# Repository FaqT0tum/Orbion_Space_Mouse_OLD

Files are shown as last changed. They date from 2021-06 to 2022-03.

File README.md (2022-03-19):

# Orbion The OpenSource Space Mouse






### Next news
- Neopixel Settings
- Scroll improvement
- Joystick improvement (the negative axes appear to have oversized values)
- Generic improvements (indicated by users)
- Cover screen improvement
- 3 rear button
- New knob support sistem

- The next firmware will be released in the (Release) section, on a date to be determined

<h1> THIS VERSION IS OBSOLETE </h1>

### go [here](https://github.com/FaqT0tum/Orbion_3D_Space_Mouse) for the new version

If you want to follow the live updates come to [Discord](https://discord.gg/tgut7grRTV)

### Version now available
- Body 2.2 (09/02/2022)
- Firmware 0.26.2 (13/02/2022)

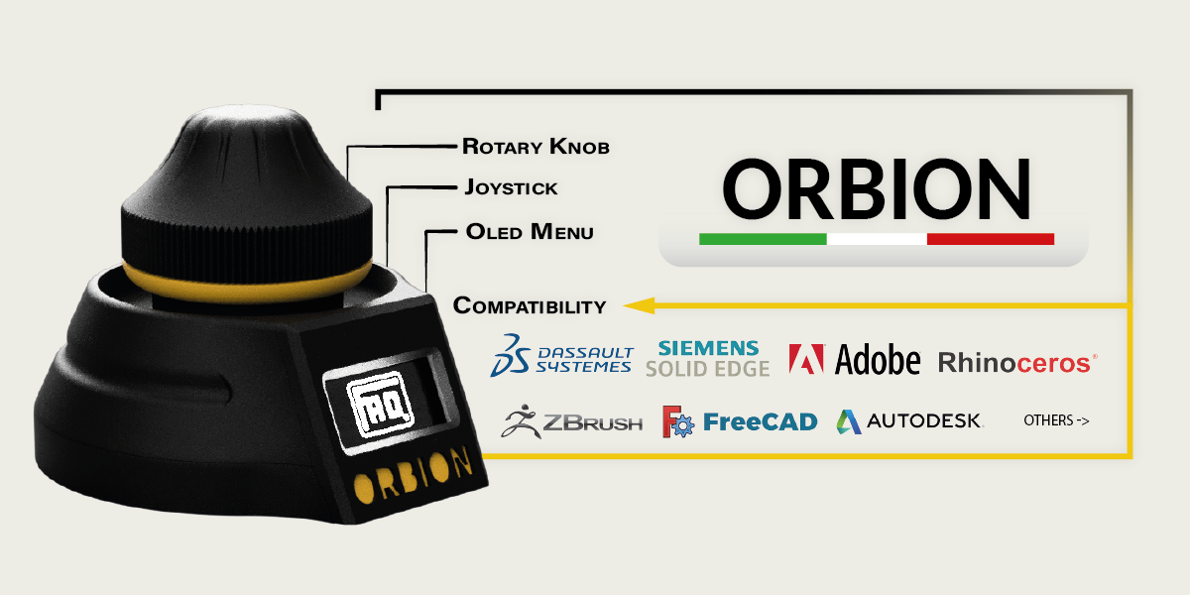
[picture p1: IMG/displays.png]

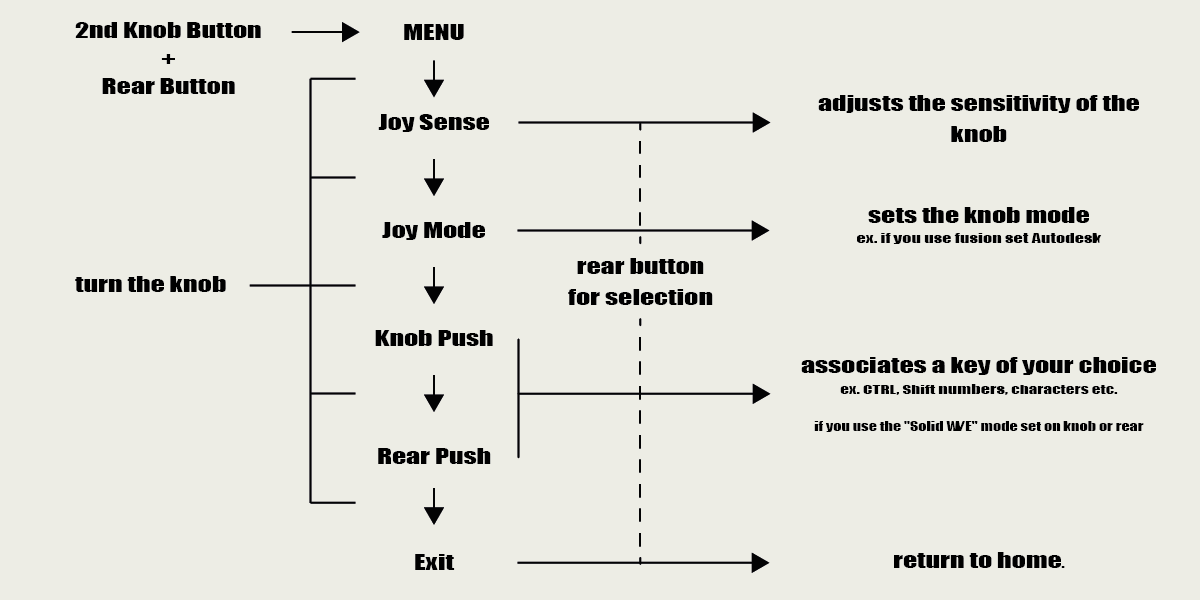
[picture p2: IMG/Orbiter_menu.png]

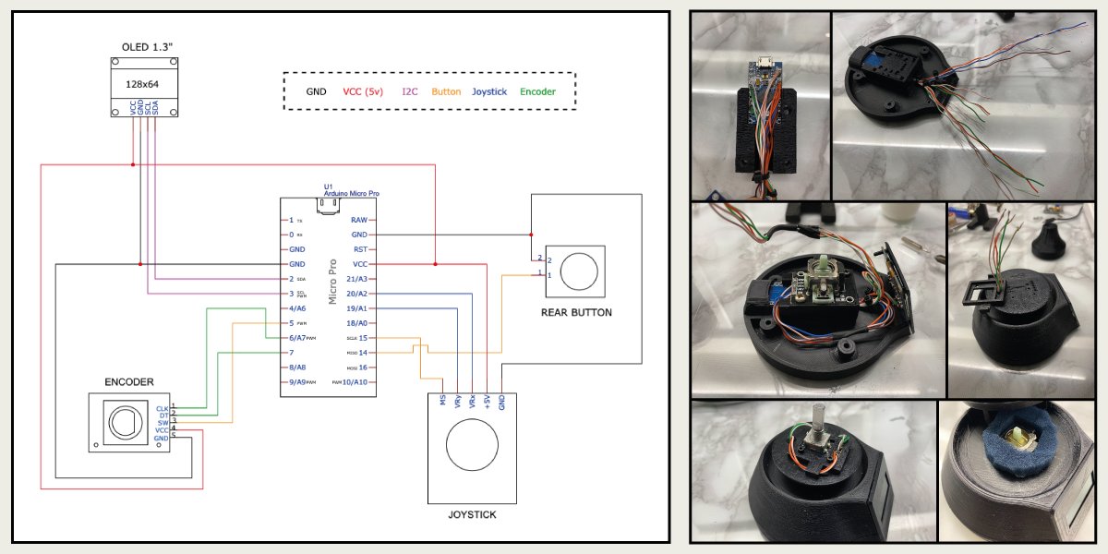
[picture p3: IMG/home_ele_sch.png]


## Cushion to be created in TPU to replace the FOAM. Designed by HiNATA

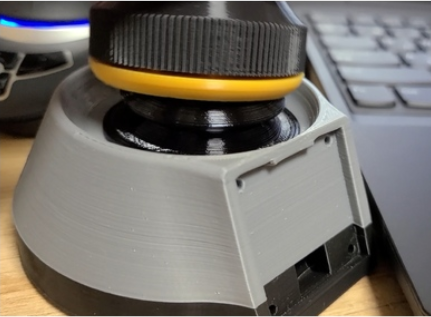
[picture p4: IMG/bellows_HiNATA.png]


Orbion (https://www.youtube.com/watch?v=NqHIdklkzfw&t "Orbion")

# PAY ATTENTION

Please note that only Rev2 is taken into consideration

For problems caused by badly produced components and wrong heights due to the calibration of printers not created Tickets as they are unique problems and not attributable to the project.

To ensure greater precision and fluidity it is recommended to put a foam ring under the knob (see photo above) and dielectric lubricant in the joystick!

If you notice that your joystick goes in different directions, you can change the direction, swapping the cables VRx and VRy or alternatively the variables horzPin and vertPin in the sketch (Find the joystick section above)

Before printing pay attention to the center distance of the encoder holes, 2 more diffuse sizes are available, 14mm and 17mm (file Enc_holder & Knob_axis)

I would like to point out that, if you use ABS it is good to know that some dimensions will not be correct if you do not take the usual precautions to the problem of shrinkage
In any case, make sure that your printer has the correct dimensional parameters

# Social

- [Instagram](https://www.instagram.com/faq_t0tum/)
- [Discord](https://discord.gg/tgut7grRTV)
- [YouTube](https://www.youtube.com/channel/UCHJ_528ZI0BcSU-QA8kIJlg)
- [PrusaPrinter](https://www.prusaprinters.org/social/218145-faqtotum/about)

# Buy me a coffee

The ORBION project is OpenSource so if you have the pleasure of supporting my next works I will be grateful fot the coffee.  
[PayPal](https://www.paypal.me/MattiaRusso308?locale.x=it_IT)

# Compatibility

Cad & 3D sculptors supported (continuously updated):
- Fusion360
- Autoocad
- SolidWork
- Solid EDGE
- Onshape
- Ansa
- ZBrush
- Blender
- Adobe Suite
- Rhino
- FreeCAD

# BOM

Componets:
- M3x15 (3pcs)
- M3x6 or M3x8 (2pcs)
- M3x10 (4pcs)
[M3 Kit](https://s.click.aliexpress.com/e/_9R4lDe)
- [Insert 5x4 or 5x5 (Diameter x Height) M3 (10pcs)](https://s.click.aliexpress.com/e/_9yVx2u)
- [Oled 1.3" I2C](https://s.click.aliexpress.com/e/_AtYDV6)
- [Encoder (KY-040)](https://s.click.aliexpress.com/e/_AmjV9a)
- [Joystick (KY-023)](https://s.click.aliexpress.com/e/_A8hY9K) (important: the joystick shaft must be 4mm)
- [Arduino Pro Micro](https://s.click.aliexpress.com/e/_AYt9zi) ATTENTION: It is essential to use ARDUINO PRO MICRO with ATMEL32U4 processor
- [Push Button 8mm](https://s.click.aliexpress.com/e/_ADGxZS)
- [Cable 28awg](https://s.click.aliexpress.com/e/_A6xGln)
- Foam

# License 
### [Attribution-NonCommercial-NoDerivatives 4.0 International](https://creativecommons.org/licenses/by-nc-nd/4.0/)
<br />

You are free to:
- Share — copy and redistribute the material in any medium or format

Under the following terms:
- Attribution — You must give appropriate credit, provide a link to the license, and indicate if changes were made. You may do so in any reasonable manner, but not in any way that suggests the licensor endorses you or your use.
- NonCommercial — You may not use the material for commercial purposes.
- NoDerivatives — If you remix, transform, or build upon the material, you may not distribute the modified material.

### If you have any other MODs you want to share, 
### log into the [Discord](https://discord.gg/tgut7grRTV) channel and contact me to add into "Yours_Creations"

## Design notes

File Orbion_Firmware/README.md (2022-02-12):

# Update 0.26.2

- improved scrolling in the menu
- Added a key combination to access the menu, to avoid accidental entry (Rear Button + second central button of the knob)

# Upload Orbion FIRMWARE on MCU

- Download and Installa Arduino IDE https://www.arduino.cc/en/software
- launch Arduino IDE and open the .ino file in the Orbion_FW_vX.XX folder (the icon.h file is also essential, so include it in the folder where the .ino file)
- Add the .ZIP libraries present in Orbion_FW_vX.XX/Library (Sketch -> #include library -> add library from .zip)
- select the board to use (Tools -> Board -> Arduino AVR Board -> Arduino Micro)
- select the port of your arduino (Tool -> Port -> (Arduino Micro) )
- now you are ready to upload the Firmware (Sketch -> Upload)
- now enjoy :)

#### Download only one version of the .ino file, for example the latest

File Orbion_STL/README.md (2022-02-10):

# NEW UPDATE (Rev. 2.2)

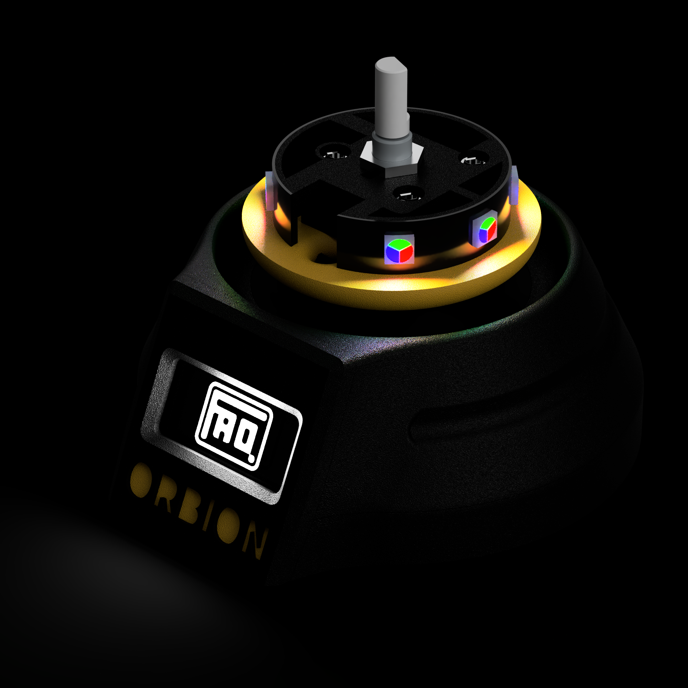
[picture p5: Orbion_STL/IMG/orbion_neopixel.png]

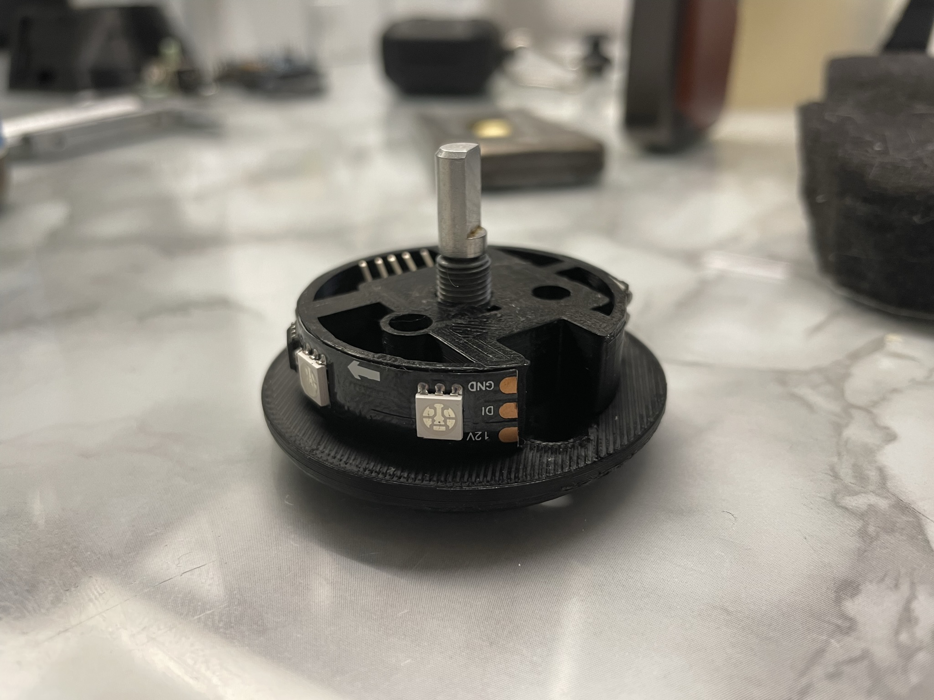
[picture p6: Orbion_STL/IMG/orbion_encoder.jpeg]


#### Don't mind the 12v led strip, it was just a fitting test
#### But the new Enc_holder remains essential to improve stability and rotation precision, so even without neopixels, the Enc_holder and Knob_axis_XXmm files must be printed.
### The Neopixels (WS2812b) have not been implemented yet, which will happen later

# Slicer

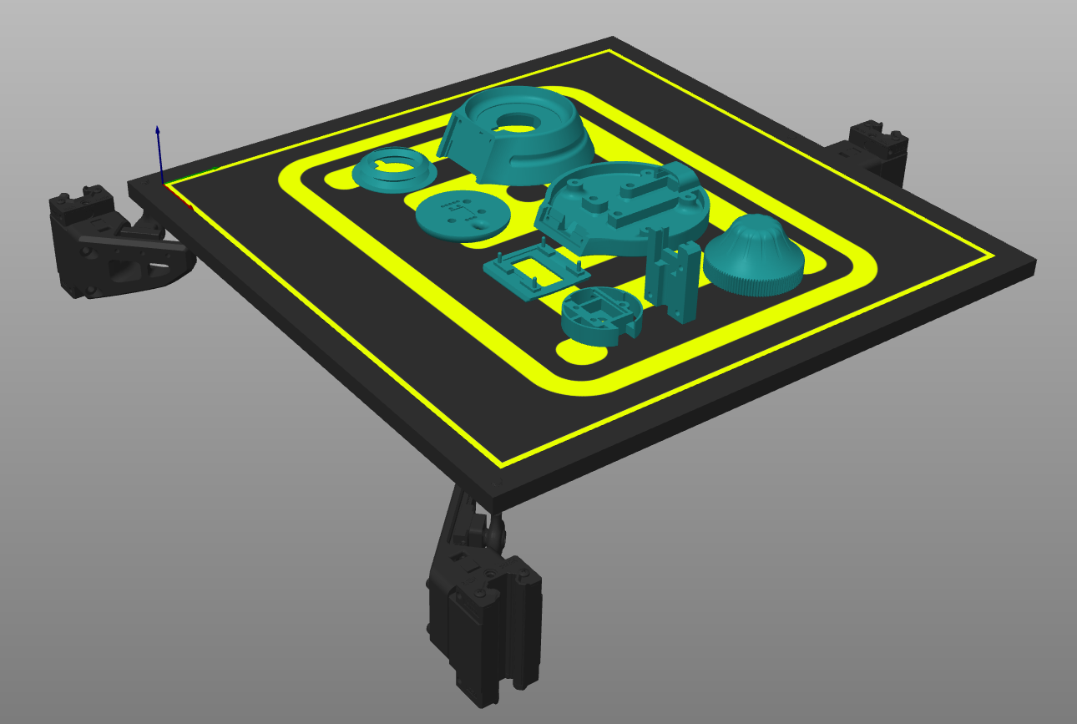
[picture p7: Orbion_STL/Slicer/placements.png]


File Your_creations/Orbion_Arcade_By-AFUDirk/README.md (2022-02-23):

# Orbion MOD (Arcade) With 6 Push button By AFUDirk

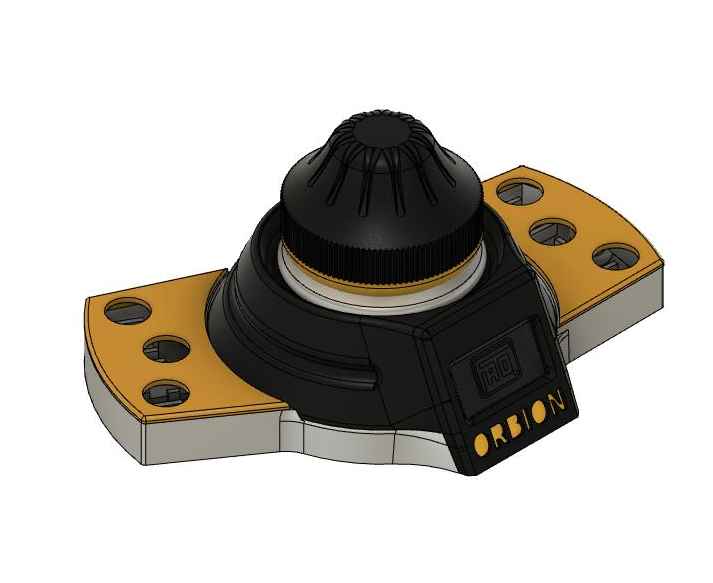
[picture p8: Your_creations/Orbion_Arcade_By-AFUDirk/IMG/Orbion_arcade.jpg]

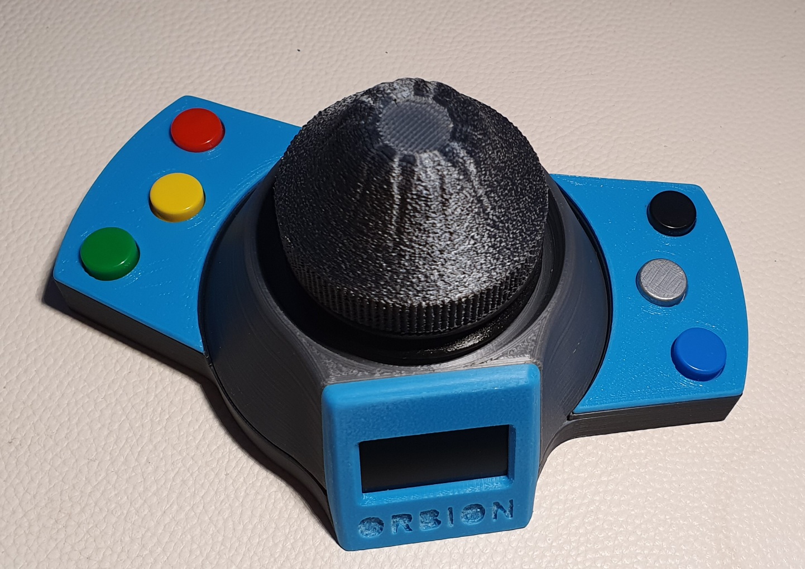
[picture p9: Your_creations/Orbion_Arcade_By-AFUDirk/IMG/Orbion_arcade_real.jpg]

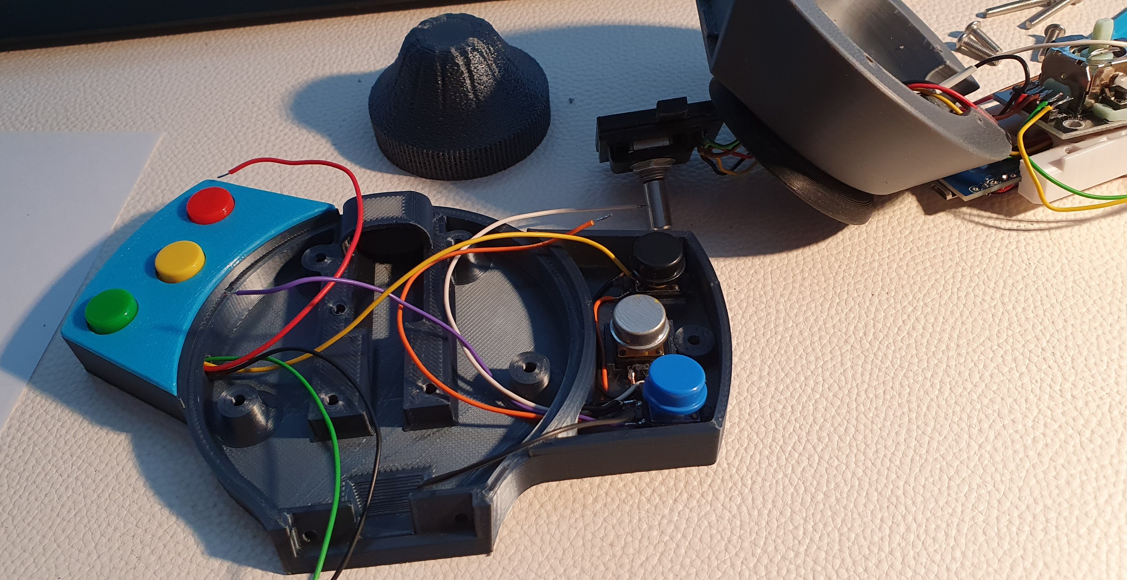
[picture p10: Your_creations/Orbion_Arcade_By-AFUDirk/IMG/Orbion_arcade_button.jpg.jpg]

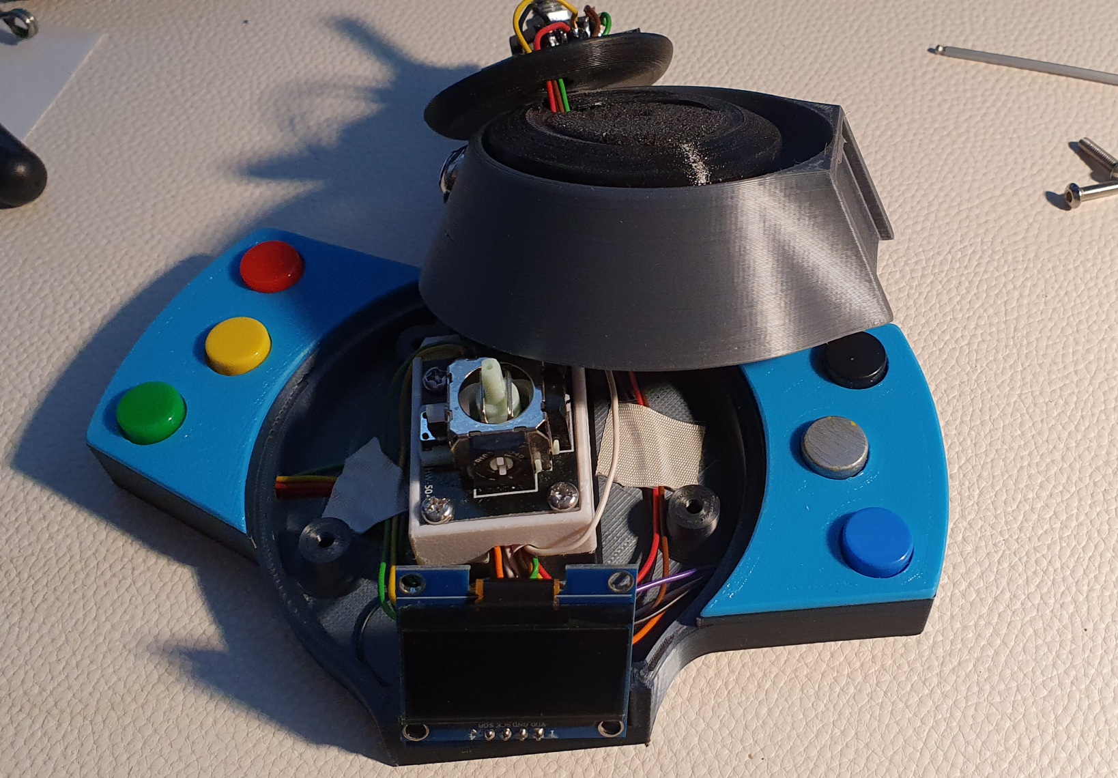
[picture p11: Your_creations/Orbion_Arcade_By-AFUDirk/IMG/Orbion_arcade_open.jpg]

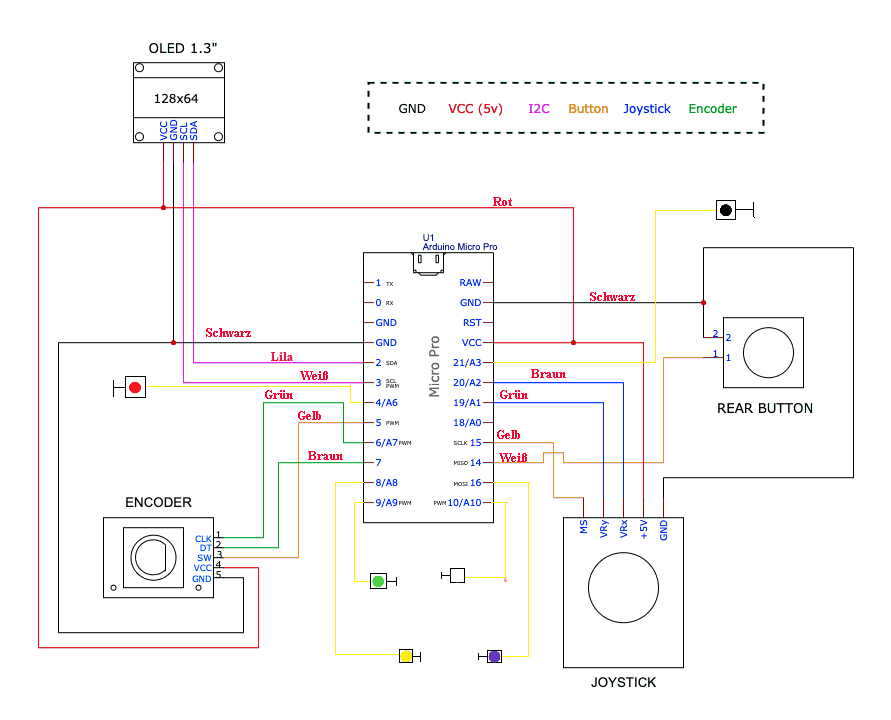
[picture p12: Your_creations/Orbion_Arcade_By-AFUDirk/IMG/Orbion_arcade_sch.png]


# BOM

Componets:
- M3x15 (3pcs)
- M3x6 or M3x8 (2pcs)
- M3x10 (4pcs) 
[M3 Kit](https://s.click.aliexpress.com/e/_9R4lDe)
- [Insert 5x4 or 5x5 (Diameter x Height) M3 (10pcs)](https://s.click.aliexpress.com/e/_9yVx2u)
- [Oled 1.3" I2C](https://s.click.aliexpress.com/e/_AtYDV6)
- [Encoder (KY-040)](https://s.click.aliexpress.com/e/_AmjV9a)
- [Joystick (KY-023)](https://s.click.aliexpress.com/e/_A8hY9K) (important: the joystick shaft must be 4mm)
- [Arduino Pro Micro](https://s.click.aliexpress.com/e/_AYt9zi) ATTENTION: It is essential to use ARDUINO PRO MICRO with ATMEL32U4 processor
- [Rear push Button 8mm](https://s.click.aliexpress.com/e/_ADGxZS)
- [Push Button 8mm 6pcs](https://s.click.aliexpress.com/e/_A5RW7d)
- Foam
- Cushion (Printable in TPU)

I designed a macro keyboard that extends the ORBION_SPACE_MOUSE,
because the Arduino installed there still had many unused connections.
I have assigned the six keys with the following functions that are used frequently.
-L for line
-C for circle
-R for rectangle
-E for extrusion
-Q for push/pull
-Shift and 1 for four views preview

The buttons can be assigned as desired in the Arduino code.
The attached Arduino code refers to version 0.26.03.
The attached fusion file can be inserted into the existing project and connected to the base of the ORBION.
The two halves of the keyboard can be used if necessary depending on which version you use (MICO-USB or USB-C).
Please don't forget to add the two holes to the ORBION to attach the cables to perform.

### If you need a hand and clarification you will find the creator on 
[Discord](https://discord.gg/tgut7grRTV)

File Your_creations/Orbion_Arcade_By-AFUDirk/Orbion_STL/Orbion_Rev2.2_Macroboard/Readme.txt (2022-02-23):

I designed a macro keyboard that extends the ORBION_SPACE_MOUSE,
because the Arduino installed there still had many unused connections.
I have assigned the six keys with the following functions that are used frequently.
L for line
C for circle
R for rectangle
E for extrusion
Q for push/pull
Shift and 1 for four views preview

The buttons can be assigned as desired in the Arduino code.
The attached Arduino code refers to version 0.26.03.
The attached fusion file can be inserted into the existing project and connected to the base of the ORBION.
The two halves of the keyboard can be used if necessary depending on which version you use (MICO-USB or USB-C).
Please don't forget to add the two holes to the ORBION to attach the cables to perform.

I used these buttons:
GTIWUNG (12 x 12 x 7.3mm) Pushbutton Switch, Micro Momentary Pushbutton Switch,
4 pin micro switch, with cap for Arduino.
AMAZON: https://www.amazon.de/dp/B08VNB6BX5/ref=cm_sw_em_r_mt_dp_BYXSJA3T0259SFX7PPZY?_encoding=UTF8&psc=1

or

ALIEXPRESS:
https://www.aliexpress.com/item/32834276752.html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 %22sku_id%22%3A%2265072909447%22%7D&pdp_pi=-1%3B1.54%3B-1%3B-1%40salePrice%3BEUR%3Bsearch-mainSearch

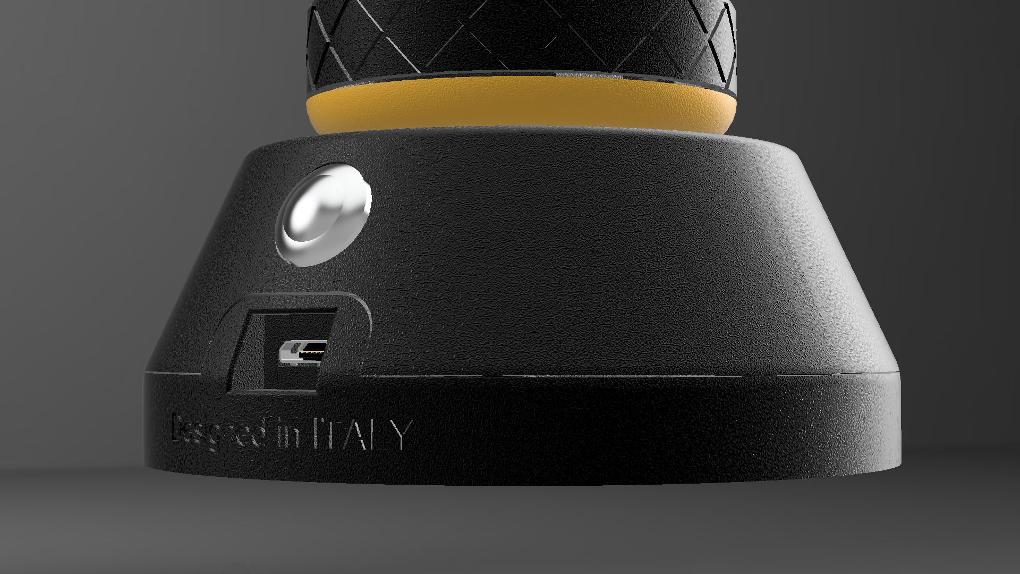
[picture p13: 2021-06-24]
IMG/Orbion_rear.png

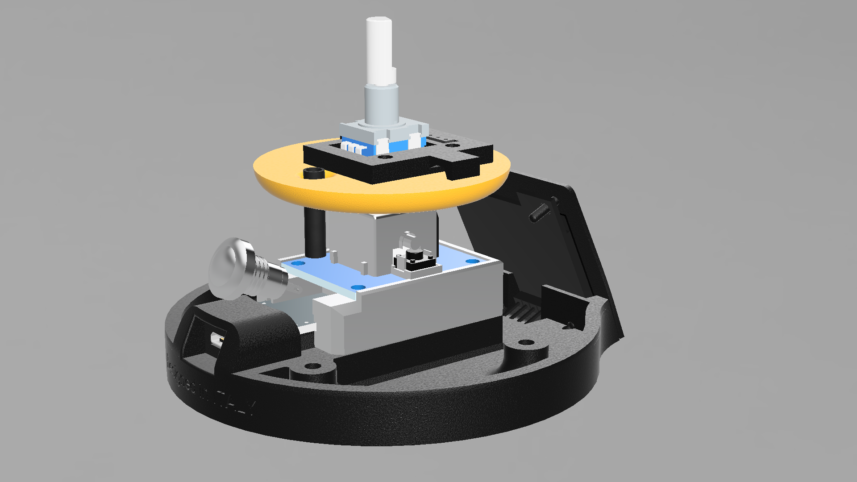
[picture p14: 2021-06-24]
IMG/Orbion_inner.png

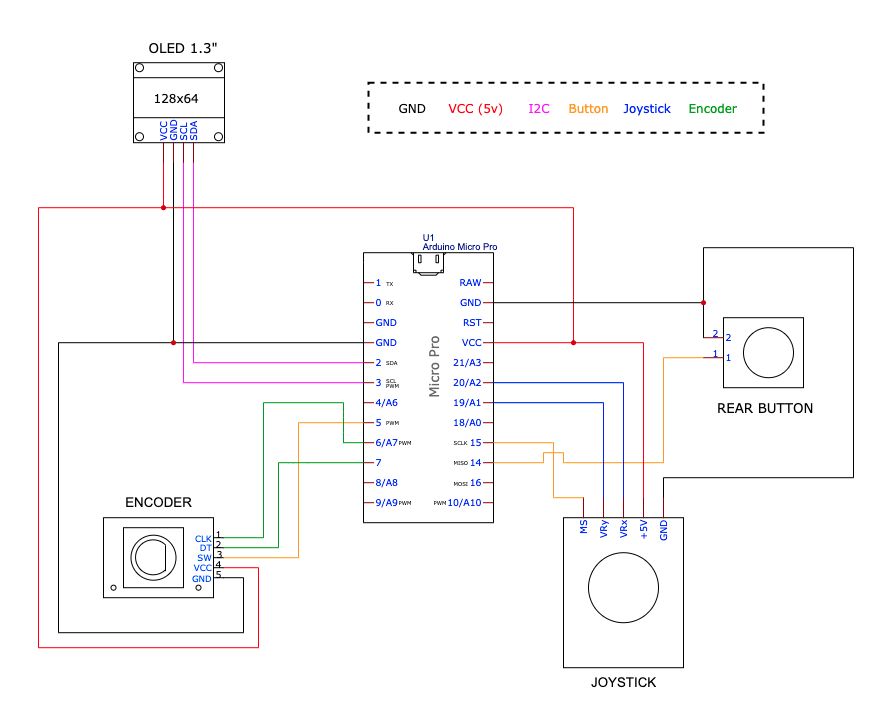
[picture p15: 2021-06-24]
IMG/Orbion_(SCH).png

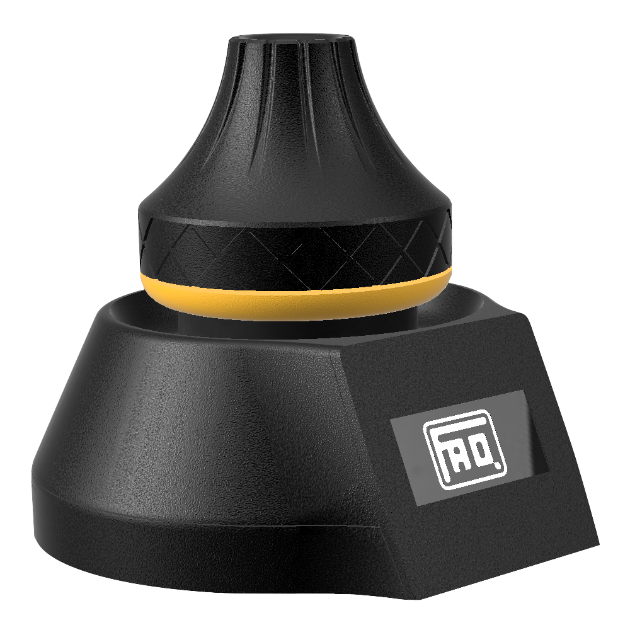
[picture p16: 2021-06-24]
IMG/Orbion.png

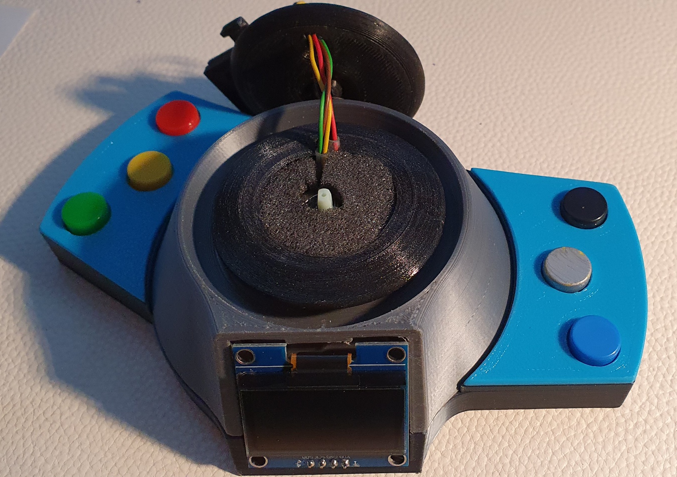
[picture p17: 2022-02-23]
Your_creations/Orbion_Arcade_By-AFUDirk/IMG/Orbion_Balg.jpg

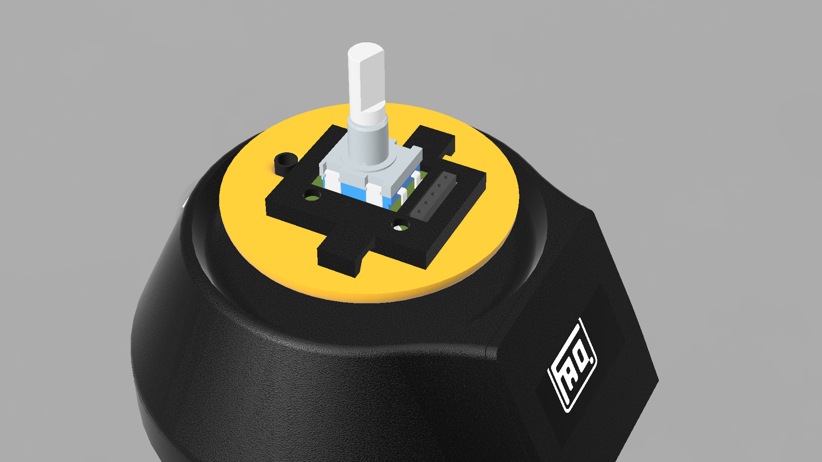
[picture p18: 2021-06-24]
IMG/Orbion_enc.png

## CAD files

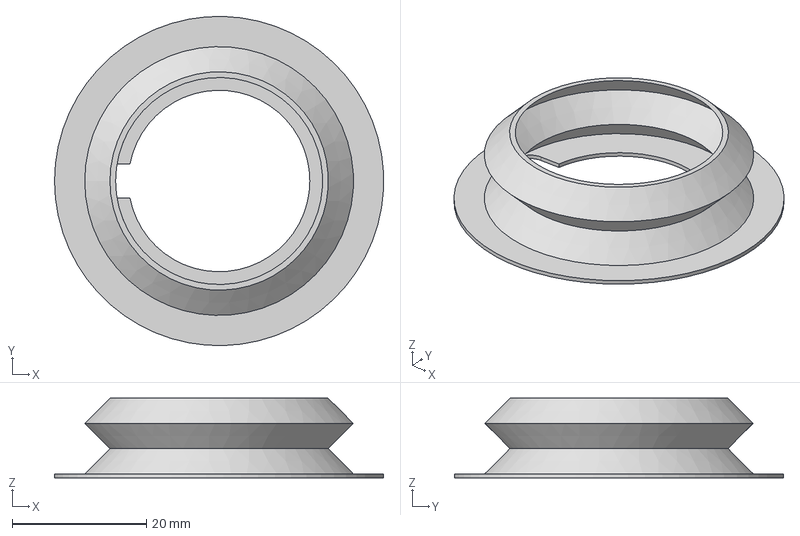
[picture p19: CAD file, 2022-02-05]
Orbion_CAD/Bellow_HiNATA.step
49.0 x 49.0 x 11.9 mm

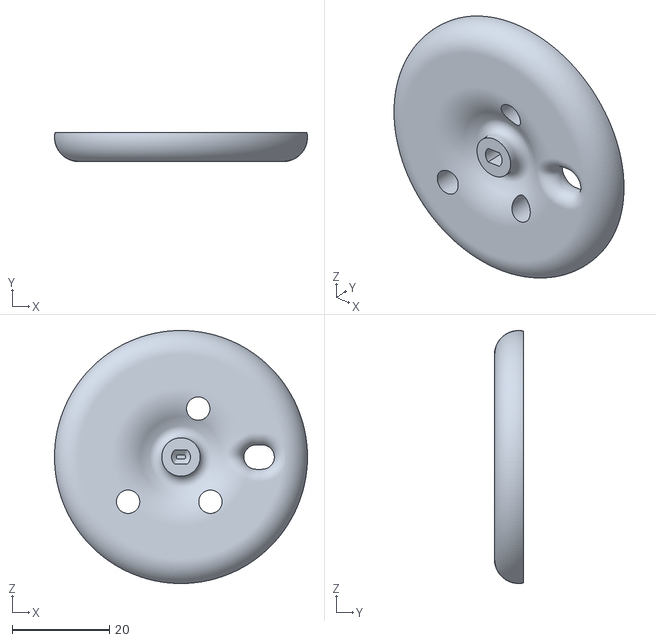
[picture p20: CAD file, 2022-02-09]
Orbion_STL/Orbion_Rev2.2/Knob_Axis_17mm.stl
52.0 x 6.01 x 52.0

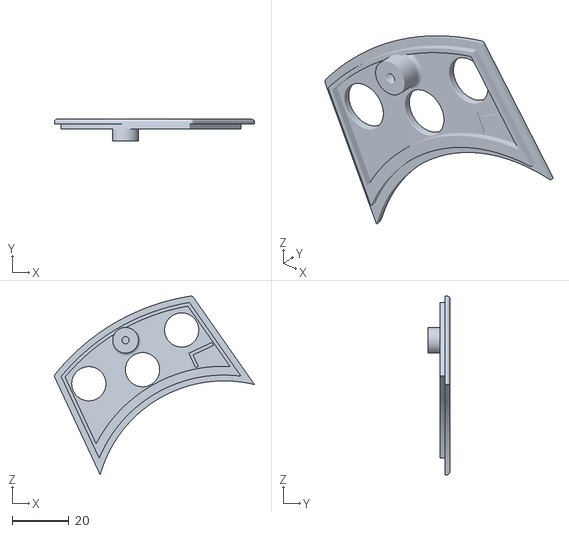
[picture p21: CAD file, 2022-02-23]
Your_creations/Orbion_Arcade_By-AFUDirk/Orbion_STL/Orbion_Rev2.2_Macroboard/Cover_left.stl
70.4 x 7.77 x 62.9

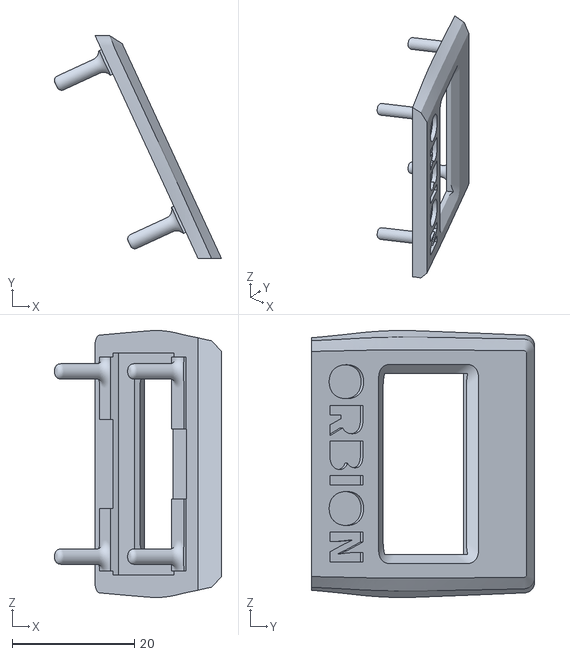
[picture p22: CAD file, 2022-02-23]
Your_creations/Orbion_Arcade_By-AFUDirk/Orbion_STL/Sceen_cover.stl
27.4 x 36.6 x 43.7

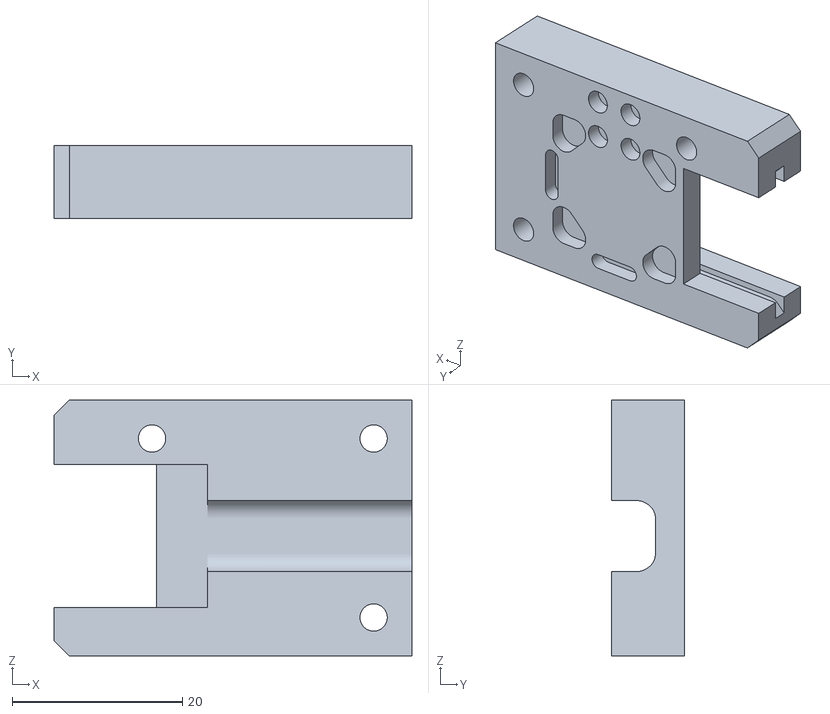
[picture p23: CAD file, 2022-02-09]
Orbion_STL/Orbion_Rev2.2/Supp_ele_Micro_USB.stl
42.0 x 8.55 x 30.0

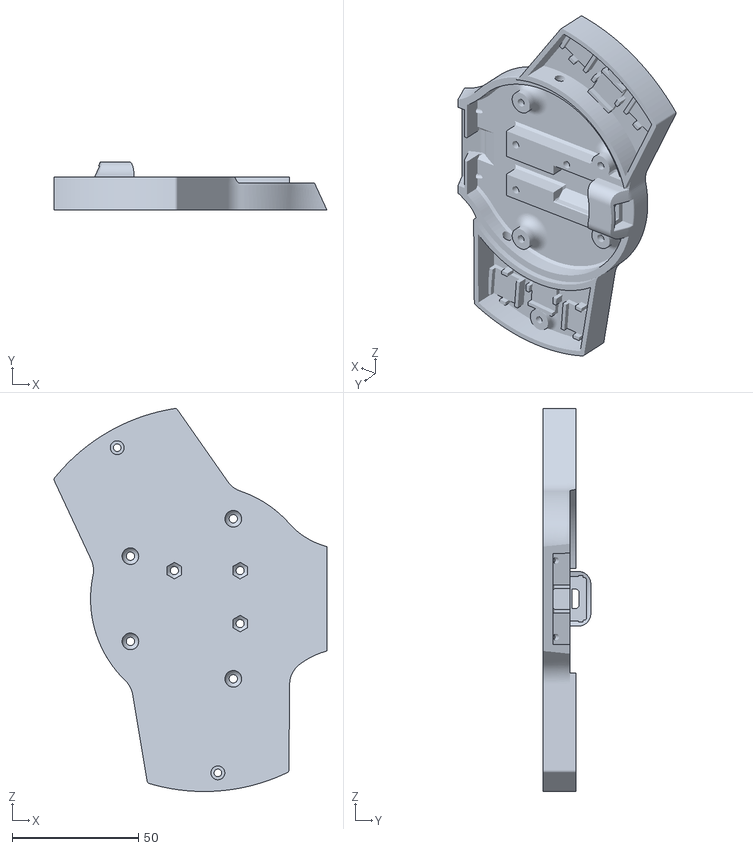
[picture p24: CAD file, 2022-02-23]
Your_creations/Orbion_Arcade_By-AFUDirk/Orbion_STL/Base_Macroboard.stl
108.0 x 18.9 x 151.7

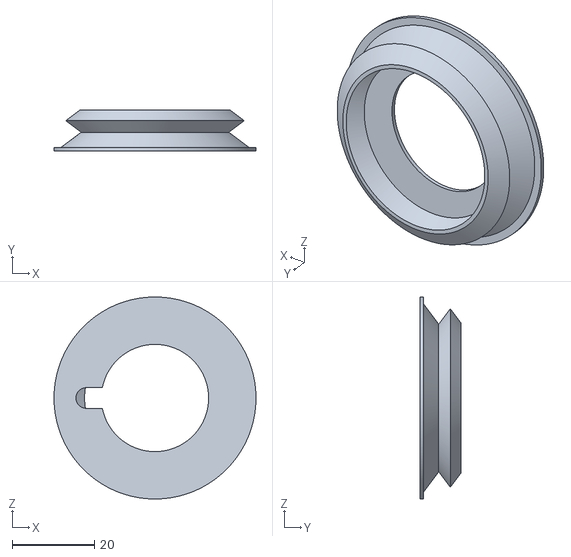
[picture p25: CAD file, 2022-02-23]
Your_creations/Orbion_Arcade_By-AFUDirk/Orbion_STL/Orbion_Rev2.2_Macroboard/bellows.stl
49.0 x 9.89 x 49.0

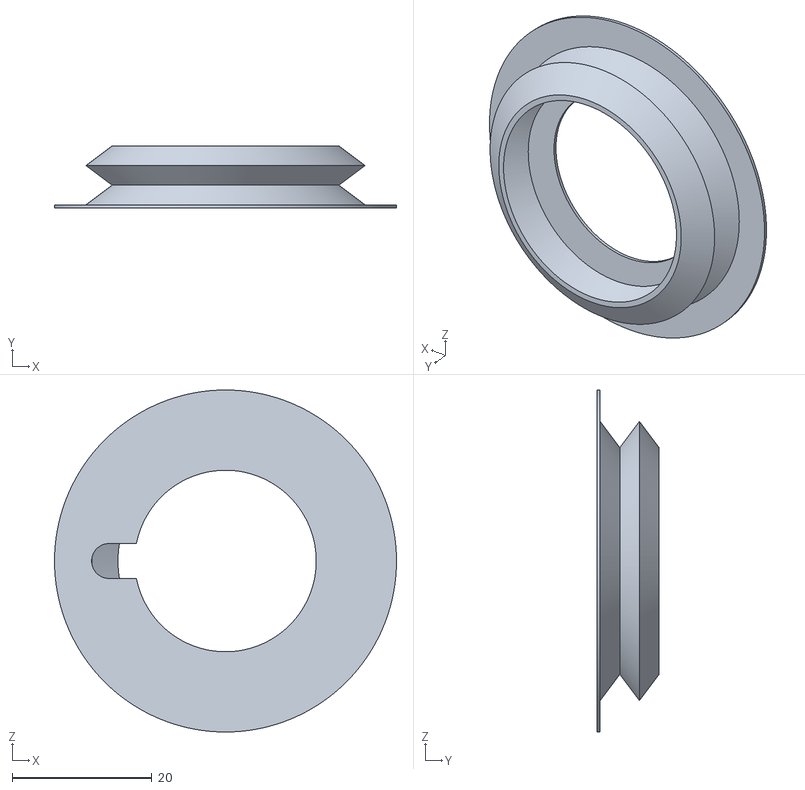
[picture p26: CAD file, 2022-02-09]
Orbion_STL/Orbion_Rev2.2/Cushion_HiNATA.stl
49.0 x 8.89 x 49.0

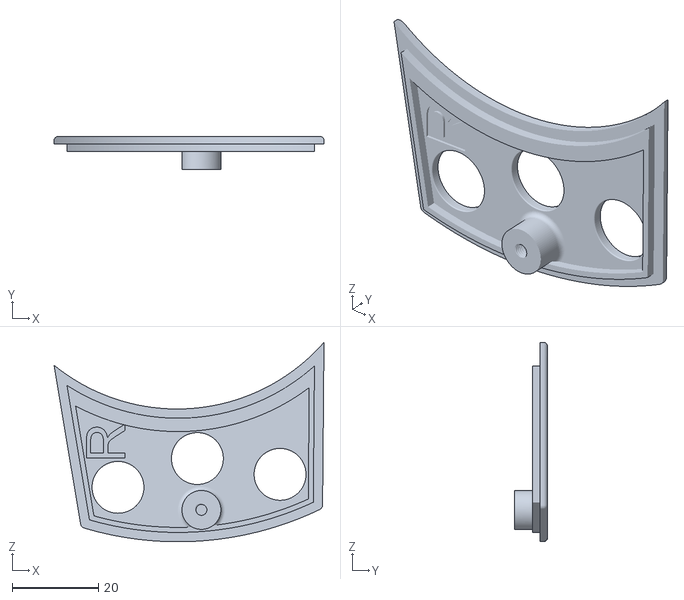
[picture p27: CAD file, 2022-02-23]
Your_creations/Orbion_Arcade_By-AFUDirk/Orbion_STL/Oberteil_re.stl
62.7 x 7.77 x 46.3

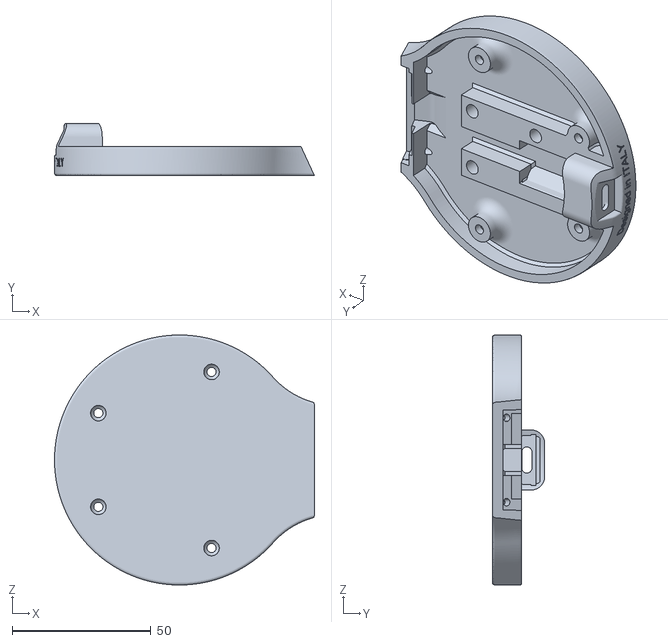
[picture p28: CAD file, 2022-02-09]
Orbion_STL/Orbion_Rev2.2/Base_TypeC_BETA.stl
93.6 x 18.9 x 90.0

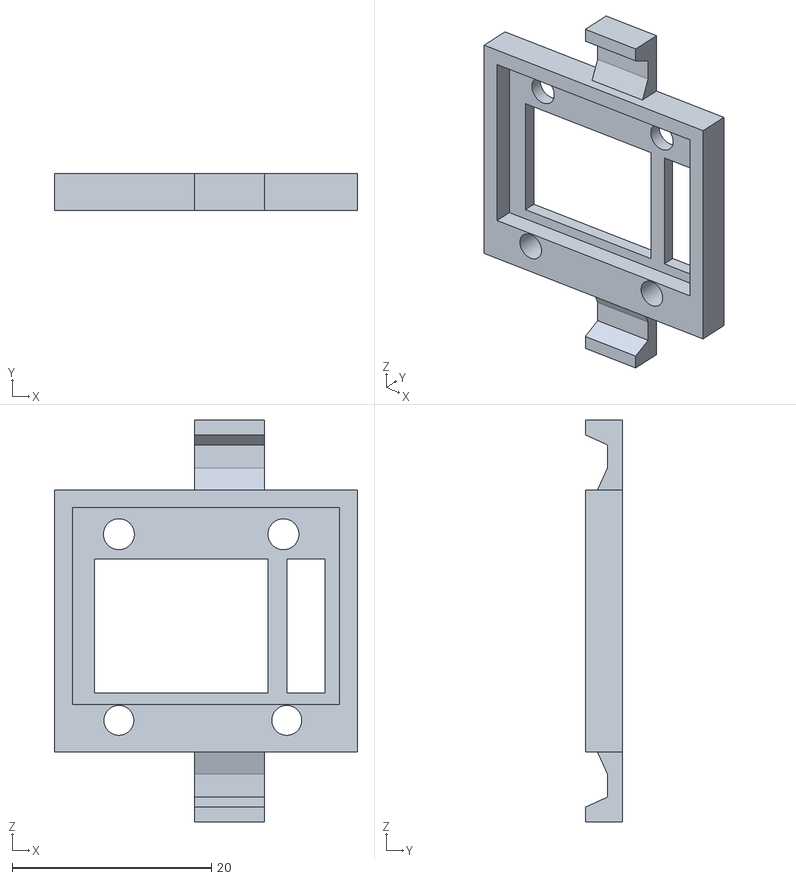
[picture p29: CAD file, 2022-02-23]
Your_creations/Orbion_Arcade_By-AFUDirk/Orbion_STL/Encoder_holder.stl
30.4 x 3.70 x 40.3

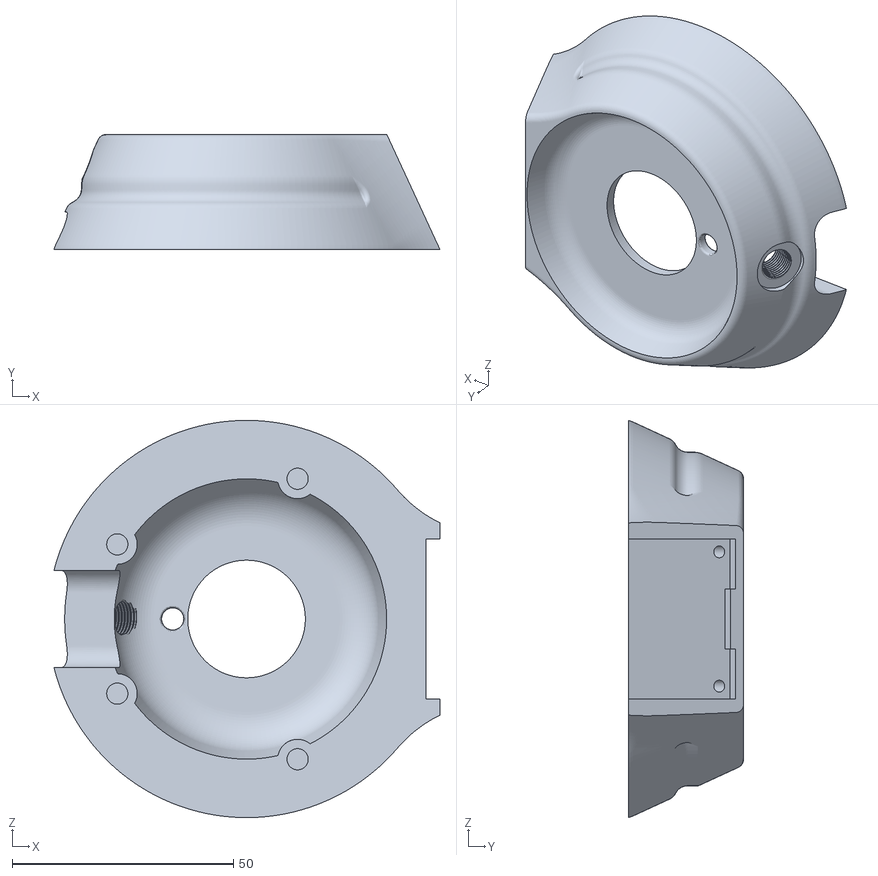
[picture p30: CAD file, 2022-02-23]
Your_creations/Orbion_Arcade_By-AFUDirk/Orbion_STL/Orbion_Rev2.1/Body.stl
87.2 x 26.0 x 89.7

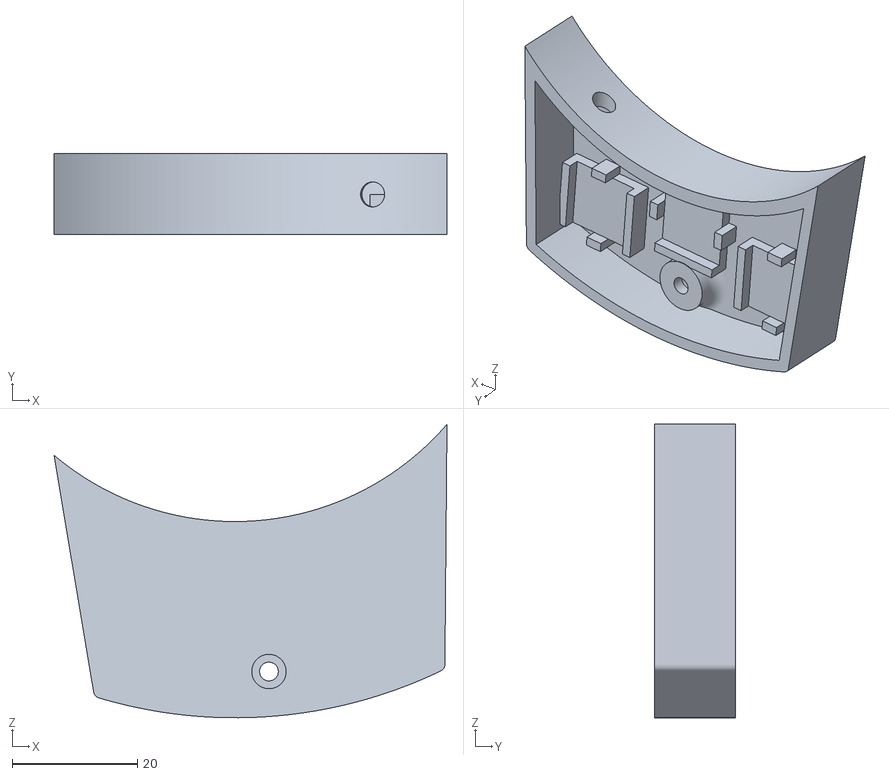
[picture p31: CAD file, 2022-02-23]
Your_creations/Orbion_Arcade_By-AFUDirk/Orbion_STL/Orbion_Rev2.2_Macroboard/Shell_Macroboard re.stl
62.8 x 12.9 x 46.9

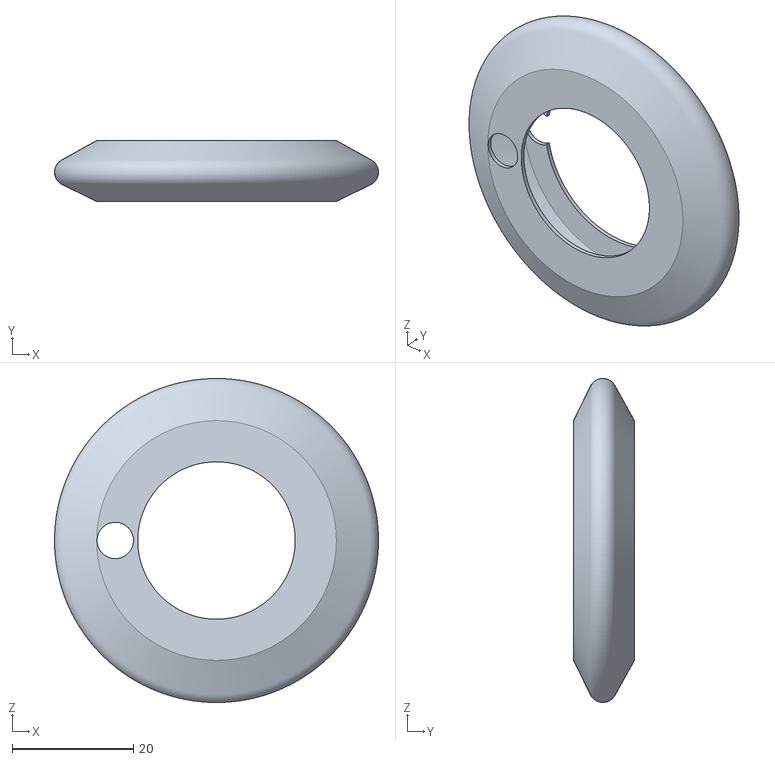
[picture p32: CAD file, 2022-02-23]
Your_creations/Orbion_Arcade_By-AFUDirk/Orbion_STL/Orbion_Rev2.1/Balg.stl
53.5 x 10.1 x 53.5

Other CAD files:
Your_creations/Orbion_Arcade_By-AFUDirk/Orbion_STL/Orbion_Rev2.1/Sceen_cover.stl
Your_creations/Orbion_Arcade_By-AFUDirk/Orbion_STL/Orbion_Rev2.2_Macroboard/Shell_MicroUSB_Macroboard.stl
Orbion_STL/Orbion_Rev2.2/Knob_Axis_14mm.stl
Your_creations/Orbion_Arcade_By-AFUDirk/Orbion_STL/Oberteil_li.stl
Orbion_STL/Encoder_holder.stl
Orbion_STL/Orbion_Rev2.1/Bellow_HiNATA.stl
Orbion_STL/Orbion_Rev2.2/Base_MicroUSB.stl
Orbion_STL/Orbion_Rev2.2/Body.stl
Orbion_STL/Orbion_Rev2.2/Enc_holder_14mm.stl
Orbion_STL/Orbion_Rev2.2/Enc_holder_17.stl
Orbion_STL/Orbion_Rev2.2/Sceen_cover.stl
Orbion_STL/Orbion_Rev2.2/Supp_ele_Type_C_BETA.stl
Orbion_STL/Sceen_cover.stl
Your_creations/Orbion_Arcade_By-AFUDirk/Orbion_CAD/Macroboard.f3d
Your_creations/Orbion_Arcade_By-AFUDirk/Orbion_STL/Base.stl
Your_creations/Orbion_Arcade_By-AFUDirk/Orbion_STL/Body.stl
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

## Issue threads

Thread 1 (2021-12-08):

button

egon1980, 2021-12-08:
when i push the button nothing happens. i'm a new bee in arduino. I ordered the exact parts that where in the list and checked the wiring multply times

FaqT0tum, 2021-12-08:
have you configured the rear key in the oled display menu?

egon1980, 2021-12-08:
i can't come in the menu

FaqT0tum, 2021-12-08:
because?

egon1980, 2021-12-08:
i don't why i can't access the menu

egon1980, 2021-12-08:
i found the problem i didn't see there was a button x y axis

FaqT0tum, 2021-12-08:
>

ah, ok ... I close the discussion with a problem solved

Closed 2021-12-08.

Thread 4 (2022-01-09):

Broken link for joystick

spuder, 2022-01-09:
Joystick (KY-023): https://s.click.aliexpress.com/e/_AM43rq2 (important: the joystick shaft must be 4mm)

This link is broken

Here are a bunch of items with the name `ky-023` but I'm not sure what you mean by the shaft must be 4mm. None of these mention how long the joystick shaft is

https://www.aliexpress.com/af/joystcik-ky-023.html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

Could you point out which one you would buy?

FaqT0tum, 2022-01-09:
Thank you for reporting the issue. Now it's been fixed

Closed 2022-01-09.

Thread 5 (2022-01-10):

BOM doesn't include screws to attach encoder holder to knob base

valinhorn, 2022-01-10:
BOM doesn't include the two m3 screws required to attach the encoder holder and encoder to the knob base

FaqT0tum, 2022-01-15:
Thanks ... I'll fix it

Closed 2022-01-15.

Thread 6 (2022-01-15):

Can I add RGB

Kretdiop, 2022-01-15:
Can I add RGB to this project if one PWM is used by OLED ?

FaqT0tum, 2022-01-15:
explain yourself better, I didn't understand what you mean

Kretdiop, 2022-01-15:
To connect RGB i need 3 free PWM and GND. But in Diagram i see only 2 free PWM

FaqT0tum, 2022-01-15:
Use WS2812 LEDs, they only need 3 pins, GND 5V and one digital pin

Closed 2022-01-20.

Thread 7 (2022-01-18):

Possible enhancement to include lateral input

Stargrove1, 2022-01-18:
Not an issue, just an idea I'd like to ask about.

Arduino has two free AIs, this would allow to add a second joystick input. If the second joystick gets mounted upside down on top of the existing one, it might be possible to create a lateral input by adding both joysticks absolute value for lateral movement, while adding the values for existing input. The joysticks need to be connected by a kind of tube, maybe printed and glued.
See below sketch

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

FaqT0tum, 2022-01-19:
I like the idea, but in this way you would raise the knob too much, in addition to the fact that the movement will always be on a fulcrum and never linear

However, I am already working on a version with 6 axes managed by optical sensors which are the best choice for precision and reliability.

Stargrove1, 2022-01-19:
You are right, it would require to lower it down in the base. The loss in height during lateral movement would be not be very big, only ~3mm.

But if you are already working on a different solution, that's even better. What kind of optical sensor will be used?

FaqT0tum, 2022-01-19:
3mm can be many.  for the optical sensor for now I can tell you a little, I am still looking for an optimal solution for the simplified realization and functionality

Stargrove1, 2022-01-19:
I hope to see the upgrade soon. Thank you for your effort

Closed 2022-01-19.

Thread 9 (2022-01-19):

Knob axis base mount (the thing you put on the joystick-shaft)

binxyde, 2022-01-19:
Hi there!

You did an awesome job with this! I love your precise design an especially the fact that you only used modules that are available quick and easy! :)

The last days I rebuilt this cool space mouse, and I would like to suggest a little mod on the knob axis part.
I made the mount for the joystick-shaft 3mm longer and made a little bit more space for it inside. 0.2mm in every direction.
Then you can push it easily onto the joystick and you have a little bit space to calibrate the alignment to the base.
A drop of hot-glue will hold it tight.

With the original design I destroyed one of my joystick modules while trying to push it onto the shaft :/

Best wishes,
binxyde

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

stevedee78, 2022-01-21:
Can you share the STL from your Knob_axis, please?

FaqT0tum, 2022-01-21:
the holes are very dependent on the print quality, if the printer creates small blobs, internal seams or is not properly adjusted, the holes may be wider or narrower ... I assume this is your case as it is the only signal that has arrived.  all files have already been released in the STL section, including the REV.  2

binxyde, 2022-01-21:
@FaqT0tum yeah...the printer (creality cr-10s pro) was calibrated just before that print...but i saw that i have forgotten to use your extrusion width parameters. maybe thats the fault.

@stevedee78 i can't attach stl files here. But FaqT0tum published the fusion file. so its an easy thing to mod it by yourself.

Closed 2022-01-21.

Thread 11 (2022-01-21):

V2 Step file missing?

mini-ninja-64, 2022-01-21:
Hello!

I noticed that the Orbion V2 has released and was very excited, but noticed that the step file was not available for V2 yet.

Will this be available soon?

FaqT0tum, 2022-01-21:
forgive me, I thought I uploaded them.  give me time and I'll load them

mini-ninja-64, 2022-01-21:
No need to apologize, thank you so much for your work on this its brilliant! ❤️

Closed 2022-01-21.

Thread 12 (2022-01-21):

need for 2 versions of the joystick too: different mounting holes, different joystick rod

netweaver1970, 2022-01-21:
Hi,
small question, just this morning I made a modification to the v1.1 knob axis for a different (same name as far as I know) joystick. This was the joystick I had in my arduino stuff drawer. It has a thin 2x1 mm metal rod on top instead of the thick plastic stub you made the design for. I used the V1.1 Fusion360 file.
And just then I saw you released 2.0, with 2 variants for different encoders :)

I could add another variant for my (and maybe other's) joystick. I could do it using the STEP file but a bit cleaner would be to use the Fusion 360 file. If you don't want to release the Fusion file yet on Github, maybe you can share it using Fusion360 directly, I'll only add the new variant of the knob_axis and the corresponding mounting hole changes. All images below are from the STEP file.

this is the situation with the 2 joysticks superimposed, you can see the holes don't align.
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

And this is the top part, the rods are totally different. My joystick is active:
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

If you would like to do it by yourself, it's also fine, this is the source link for the 3d model: https://grabcad.com/library/dual-axis-xy-joystick-module-with-push-button-1

Thanks for the good work.

Cheers.

FaqT0tum, 2022-01-22:
Hello, everything has been released, unfortunately I forgot it due to sleep. Unfortunately in this case I will not release any variant because this joystick is not good for mechanical reasons
However, I appreciate your availability. thank you very much

drakengard780, 2022-01-30:
hi i have the same joystick i modified the project for the 14 mm. thise is the [https://www.thingiverse.com/thing:5224533](url)

Closed 2022-01-22.

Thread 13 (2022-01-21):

Arduino firmware upload issue

gti1984, 2022-01-21:
Hello and first thanks for your work.

I'm new in Arduino world and i have an issue.
I bought the Leonardo Pro Mini from your link but have this message when uploading the firmware.

Could you help me ?

Thanks
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

FaqT0tum, 2022-01-22:
Before starting I suggest you watch some videos on arduino, your problem seems to be the incorrect serial port.

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

Closed 2022-01-26.

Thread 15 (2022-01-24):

axes wrong

kzipp89, 2022-01-24:
Hi.
it looks like my axles are upside down. if I press up, it moves to the right. below = left left = below right = up. at which points in the code can I adjust this?

Ok i found. And work. Sry...

U made nice job.

Clay2F, 2022-01-24:
/////////////// JoyStick ///////////////////

int horzPin = A2;         // Pin Analog output of X        <------------
int vertPin = A1 ;        // Pin Analog output of Y        <------------
int joyButt = 15;         // Pin Joystick Button           <------------

Here you must Change the horzPin number nas the vertPin number

FaqT0tum, 2022-01-26:
Problem solved

Closed 2022-01-26.

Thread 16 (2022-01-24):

Not Recognised

Aesavyx, 2022-01-24:
After flashing the firmware, the pc calls the device "Unknown USB Device" in device manager and it no longer shows on the COM ports. The screen works but it doesn't do anything in any programs.

Clay2F, 2022-01-25:
What program did you use to create the sketch?
I created mine with VScode and PlatformIO and had to add the libraries manually or use others.

Aesavyx, 2022-01-25:
I used arduino IDE.

FaqT0tum, 2022-01-26:
> Ho usato arduino IDE.

the problem has been solved?

Aesavyx, 2022-01-26:
I think I just had a faulty pro micro

drakengard780, 2022-01-27:
Same problem . After flash code.not recognize . I can t reflash

edifabio-72, 2022-01-28:
Something similar happened to me too. I solved it by disconnecting and reconnecting the usb cable. The arduino board should change usb port. It should now reflash correctly.

drakengard780, 2022-01-28:
When i write code , After thise the USB no recognized . So not work . What can i do ( sto perdendo la capa 😂)

Closed 2022-01-26.

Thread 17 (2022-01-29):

zoom

bibine44, 2022-01-29:
salut
lorsque je tourne le scroll vers la droite cela dezoom et je voudrai faire l'inverse
vers la droite = zoom
vers la gauche = dezoom

FaqT0tum, 2022-01-29:
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

Please write in English to facilitate other users reading the issue ... You can reverse the direction of rotation from the sketch

FaqT0tum, 2022-01-29:
to the variable Mouse.move (0, 0, 1); the third number concerns the scroll, insert the minus sign where it is not and delete where it is, so as to reverse the rotation of the encoder

Closed 2022-01-29.

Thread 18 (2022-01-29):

Rosters encoder needs more clearance

spuder, 2022-01-29:
The rotary encoder I received has solder that slightly interferes with the print

It would be good to add a little more clearance for resistors and solder joints

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

spuder, 2022-01-29:
I printed the 14 mm version from version 2.1 and the holes are also not aligned.

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

Clay2F, 2022-01-29:
turn the printed part.
the hooks at the sides must show to the bottom

Clay2F, 2022-01-29:
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

spuder, 2022-01-29:
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

Thanks for the info. I've flipped the part and I'm finding that the holes still don't line up. I've drilled them out and trimmed excess material but it still isn't quite lined up.

Closed 2022-01-29.

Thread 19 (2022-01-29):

LCD holes are 27mm

spuder, 2022-01-29:
The lcd I received has holes that are 27mm apart, but the pegs on the front plate are closer to 29mm

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

spuder, 2022-01-30:
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

FaqT0tum, 2022-01-30:
the components in question are of low quality so even if the links are correct it may happen to receive parts with different tolerances!  therefore you can very well understand that I cannot create different components for each tolerance that the Chinese are wrong in production… there are many people who testify that the project quotas are correct, except in these cases like yours.  so please do not create a thousand issues Tricket for all your difficulties regarding the components ... Forgive me but unfortunately I am powerless in these cases

spuder, 2022-01-30:
I'm sorry if I offended you by reporting a problem. I did not intend to open "thousands of issues". I opened 2.

I'm working on solutions to these 2 problems so that other people do not have the same trouble. I apologize if you thought I was asking _you_ to fix it. That is not my intention.

How do you want me to contribute back these modified versions with fixes? Shall I upload STL fixes, or fusion 360 files?

FaqT0tum, 2022-01-30:
I'm sorry if I made you understand this, I was not offended 😋 ... mine is just a way of managing ... I like it when people contribute in order to improve the project ... if you have a real and working solution you can make a pull request or another well documented issues ticket so that I can add your improvements to the project

VinnyCordeiro, 2022-02-17:
I was about to open an issue about that because I also had alignment problems. The thing is: I bought all the components using the links provided by the author on the README.md of the version 1.1, it was to be expected that the printed parts would fit those components, as they were used as the reference. And I know that the body is already on version 2.2, but looking at the 1.1 version CAD file I can see some concerning alignment issues, like the ones on the screen, or the alignment of the holes on the encoder with the ones on the encoder holder, which are plainly wrong.

Granted, the newer version seems to use a different way to connect the encoder, but the screen is still off: the horizontal distance between the screw holes on the display is about 29 mm, while on 2.2 CAD it's 30.35 mm; and measure vertical distance is about 27 mm, while on CAD we have 28.6 mm.

I'd do these changes, but since the chosen license does not allow redistribution, I'm reporting the problem so that the author can fix it. I could ignore the license and solve all that, but I won't.

FaqT0tum, 2022-02-17:
hello, I'm sorry for the inconvenience but unfortunately for reasons of shortage of electronic components, the Chinese are spending a bit at random what is left in their warehouses.  other people have also had this problem and I want to solve it, for problems of necessity I haven't done it yet but I should have finished with the most important improvements of the firmware and encoder area.  as you can see I always try to be active in the resolutions ... I ask you if you please, can you send me the exact measurements between the holes of your oled so that I can also compare them with other users ... for other problems or doubts you can access the discord which will be easier for them speak

Closed 2022-01-30.

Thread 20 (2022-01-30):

Knob is too short

spuder, 2022-01-30:
I printed the 2.1 knob (short) and plate, but I'm finding the following problems

1. The pieces do not align
2. The Encoder is too short (I bought the exact one linked in the readme.

Did I print the wrong part? Or am I missing a piece?

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

spuder, 2022-01-30:
The knob is assumed to be 27.6 mm tall, but the part referenced in the readme are only 23mm tall

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

FaqT0tum, 2022-01-30:
the components in question are of low quality so even if the links are correct it may happen to receive parts with different tolerances!  therefore you can very well understand that I cannot create different components for each tolerance that the Chinese are wrong in production… there are many people who testify that the project quotas are correct, except in these cases like yours.  so please do not create a thousand issues Tricket for all your difficulties regarding the components ... Forgive me but unfortunately I am powerless in these cases

jerzytuleja, 2022-02-04:
The problem is that Chinese producers offer KY-040 with long (with and without threads) and short shafts, with the same name of the product.
I needed to buy 3 sets to get a proper one. I think the solution proposed by @spuder will solve the problem.

AFUDIrk, 2022-02-04:
The encoder with the long thread is better.  This can also be fastened with
the nut.  Thus, the soldering points are not so heavily loaded.  Here's my
version.  https://github.com/AFUDIrk/Orbion_Space_Mouse-2.2

Mit freundlichen Grüßen
Dirk König

Jerzy Tuleja ***@***.***> schrieb am Fr., 4. Feb. 2022, 15:59:

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

FaqT0tum, 2022-02-04:
> The problem is that Chinese producers offer KY-040 with long (with and without threads) and short shafts, with the same name of the product. I needed to buy 3 sets to get a proper one. I think the solution proposed by @spuder will solve the problem.

I am looking for a simple and universal solution

Closed 2022-01-30.

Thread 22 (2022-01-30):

difficulty in scrolling through the menus with the potentiometer

drakengard780, 2022-01-30:
ciao, i have difficult to slide in menu with potentiometer no regolary and few time scroll to exit menu

Clay2F, 2022-01-31:
I have the same issue with mine.

FaqT0tum, 2022-01-31:
have you checked the wiring and soldering? the encoder is very sensitive

Closed 2022-02-04.

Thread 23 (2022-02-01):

compilation problem

julmic, 2022-02-01:
HELLO
when i upload program
this message appear in red "too many decimal points in number"

do you have a solution
thanks

Arduino : 1.8.19 (Windows Store 1.8.57.0) (Windows 10), Carte : "Arduino Micro"

Orbion_FW_v0.26:111:41: error: too many decimal points in number

                ^~~~

exit status 1

too many decimal points in number

Ce rapport pourrait être plus détaillé avec
l'option "Afficher les résultats détaillés de la compilation"
activée dans Fichier -> Préférences.

Closed 2022-02-02.

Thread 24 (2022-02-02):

Fusion 360 Pan & Orbit

helicopterguru, 2022-02-02:
Good Afternoon.

Thank you for this great project, I am having some fun messing around with this and will soon be 3D printing the parts to assemble it.

Currently I am simply running the electronics on the bench and all is working ok, I to am seeing the rotary encode issue. But from another product I have with a similar issue, I find rotating the pot slower helps, not sure if this can help you smooth it out or not.
But my problem, or lack of understanding, is that within Fusion360 the joystick changes between pan and orbit without my input. So I am curious if I am doing something wrong, or there is a way to lock the joystick to control one or the other function?

Cheers.

Ian Contessa

FaqT0tum, 2022-02-02:
unfortunately, the encoder in question is very limited in the quality of the output, I did everything possible to make it as smooth as possible but there is a hardware limit that I cannot overcome with the code alone.  to switch from pan to orbit I have set the central key (encoder) which, if held down, makes me access the pan while moving the joystick, upon release I return to orbit mode, you can set this in the mouse settings that you access with the central button of joystick which once assembled is the second hardest click of the knob

Matt (Faq_t0tum)

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

helicopterguru, 2022-02-02:
Hey Matt.

Thank you for your time replying.

Yeah I can understand that, the product my electronics engineer designed for me using the rotary encoder also suffers similar issues.
Ah ha great, I will go an check now with holding the encoder pressed, I was trying a few things to figure out what was going on, but never thought about that. Ideally I now need to print the casing for it to make it neat.

Thanks for the fun projects.

Ian Contessa

FaqT0tum, 2022-02-02:
Imagine it's a pleasure ... this you find on the GIT home page will help you navigate the functions

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

helicopterguru, 2022-02-03:
Thanks Matt.

Well apart from the SH1106 screen which fills the space better and the 8mm button, both items on order, I have a working Orbion_Space_Mouse :-)

Two requests if I maye;

1. Within the INO file can I swap round the pan and orbit, so by deffault it orbits and then pressing the gimbal button changes to pan?
2. Would you be able to upload the STEP files of the Knob_Axis_17mm and the Screen Cover please?

The Knob_Axis I want to make about 1mm thicker at the most so I can recess the area below the potentiometer a little more as I had to cut away from material to miss the smt resistors on the back of the PCB.
The screen cover, currently I am using an SSD1306 display so I can modify it to fit that OLED and also replace the 3D printed locating pins with small screws, as mine broke away easily.

Thanks.

Ian Contessa
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

macgyverek, 2022-02-03:
Hi, I rewrite all your code and have new one with better encoder library. I want send you my code to you, but I can't found your email address.
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

macgyverek, 2022-02-03:
What I made:
1. Rewrite all code
2. Added Encoder Library
3. Added Button Library
4. Rewrite menu
5. Rewrite memory
6. Added LED backlight
7. On and auto off function
8. Pan or Orbit mode switch
9. Code optimalization

Kretdiop, 2022-02-03:
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

May i please code ? :) and some details about led ?

macgyverek, 2022-02-03:
https://drive.google.com/drive/folders/1A9cxjMF87qoBKpCRosQySsRSoncSymva?usp=sharing

I used 2x 3mm Blue LED connected in series + 10 Ohm Resistor. Kathode is connected to GND, Anode to PIN18. LCD Power is connected to PIN4. Now I can control LCD power directly from ATmega. The current is sufficient.

FaqT0tum, 2022-02-03:
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

Very interesting! as soon as I can, I hope tomorrow, I'll take a look at it, but for the LEDs I already intended to insert them, but some neopixels so that the color can be managed from the menu

macgyverek, 2022-02-03:
I changed Encoder mounting and LCD cover.
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

FaqT0tum, 2022-02-04:
>

why did you create that fixing bayonet? the knob should be kept as light as possible so as not to worsen the quality of use.

FaqT0tum, 2022-02-04:
I don't like visible screws

FaqT0tum, 2022-02-04:
I close for lack of relevant problems

macgyverek, 2022-02-04:
I didn't change position of knob I only extrude this part. Why?? Encoder play left/right between legs and encoder hausing. So encoder axis move left/right too.  When knob was rotate and gaps between base and knob was minimal, parts was rubbing.

FaqT0tum, 2022-02-04:
understood, in the mounted ones I have not encountered this oscillation problem, I will pay more attention next time so as to create a solution

helicopterguru, 2022-02-04:
Hey Guys.

I've had the knob rubbing and can see it's slightly offline on the shaft of the rotary encoder, but feel this is because of the resistors on the back of it's PCB not having enough clearance in the Knob Axis piece to sit flush on top. Thus the pot isn't exactly vertical which makes the knob rub in certain positions around the 360 degree rotation.
I've redrawn the Knob Axis, making it 0.8mm higher and this allows me to make the recesses for the underside of the pot deeper, so it should sit flat on top which will make it perpendicular to the plate.

If we can have the STEP files to play around that will be great, as working with converted STL's is a PITA.

I'm enjoying my build, looking forward to any additions.

Ian Contessa

FaqT0tum, 2022-02-04:
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

cad files have always been available in both STEP and F3D

helicopterguru, 2022-02-04:
> cad files have always been available in both STEP and F3D

DOH! Sorry, I had a senior moment and didn't look in the CAD folder.

Have a good weekend.

Ian Contessa

FaqT0tum, 2022-02-05:
> I changed Encoder mounting and LCD cover. 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

The next release will have this modification which will make the encoder more stable and solid

helicopterguru, 2022-02-05:
Hey Buddy.

I've made it even more stable again and changed the knob axis to match. Want these parts?

Ian Contessa
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

helicopterguru, 2022-02-05:
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

helicopterguru, 2022-02-05:
I'm wondering if we could make a small round PCB design that bolts to the knob axis plate, then the pot, resistors and some LED's solder to it, with a JST or other connector to bring the wires up to the underside of the knob plate. Then the rotary part is a seperate module and we can easily fit LED's up here.

Ian

helicopterguru, 2022-02-05:
![Uploading 20220205_201010.jpg…]()

blaghislain, 2022-02-05:
@helicopterguru Very intesresting.  Is it possible for you to github fork this project in order to share all your change and CAD remix?

FaqT0tum, 2022-02-05:
> 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

I'm just fixing this area up a bit. I'm adding Neopixel which will also be implemented in the menu. 3 m3 screws are enough and advance, 4 are useless, there is not much force to counter, the encoder will break first.
I believe that the final design will be a little different from this one, I want to reduce the parts for the weight and overall dimensions factor as well as making everything more universal as possible that the continuous unknowns that the Chinese create in production

helicopterguru, 2022-02-05:
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

Hey.

Nice, the neopixel will be fun.
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
AFUDIrk, 2022-02-06:
I have already constructed the bellows from the beginning. The encoder holder too, thus the solder joints are relieved.
With me a decoder broke, when I was off the Knob and sat too tightly.
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
In addition, I designed a Macro Keyboard and occupied with the buttons that are often used. I had the tried to publish, but probably did not work out.

FaqT0tum, 2022-02-06:
> I have already constructed the bellows from the beginning. The encoder holder too, thus the solder joints are relieved. With me a decoder broke, when I was off the Knob and sat too tightly. 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 In addition, I designed a Macro Keyboard and occupied with the buttons that are often used. I had the tried to publish, but probably did not work out.

I had also thought about drilling the upper part of the bellow, but so you can print it easily?

AFUDIrk, 2022-02-06:
I printed him from Filaflex 82a with Support.
But have used several assumptions until it worked.

helicopterguru, 2022-02-06:
> I have already constructed the bellows from the beginning. The encoder holder too, thus the solder joints are relieved. Then you can additionally attach him to the mother. Therefore, it is better to take a decoder with the longer axis and with thread. For me a decoder broke, when I have deducted the Knob and he sat too tightly. 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 In addition, I designed a Macro Keyboard and occupied with the buttons that are often used. I had the tried to publish, but probably did not work out.

Hey Buddy.

Ah very nice, thanks for coming in to reply.
Have you posted the bellow STL somewhere I can download to give it a go?

I'm with you now on the pot support for the main shaft, makes snese to stop any possible movement  between the solder joints holding it to the PCB. WIll try and do a similare revision.

Good addition with the macro keys, I'd like to maybe add in two for copy & paste as my keyboard has these buttons and it's getting old now so needs replacing. Is that sketch around as well for me to take a look at?

Cheers.

Ian Contessa

FaqT0tum, 2022-02-06:
> I printed him from Filaflex 82a with Support. But have used several attempts until it worked.

you still could have curdled that part with a blade

AFUDIrk, 2022-02-06:
Here is my version to find. With all changes. I hope that's ok, I do not know how to make it accessible to you.
 ](https://github.com/AFUDIrk/Orbion_Space_Mouse-2.2)

helicopterguru, 2022-02-06:
> Here is my version to find. With all changes. I hope that's ok, I do not know how to make it accessible to you. ](https://github.com/AFUDIrk/Orbion_Space_Mouse-2.2)

Awesome, thanks for sharing buddy.
When I can I'll look at the Arduino code to see what I need to import to add some macro buttons, as that could be handy from what I am seeing.

Ian Contessa

AFUDIrk, 2022-02-06:
Hello, yes I liked doing it.  I don't want to be without these macro keys
anymore.  They are very useful.

Mit freundlichen Grüßen
Dirk König

helicopterguru ***@***.***> schrieb am So., 6. Feb. 2022,
20:17:

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

FaqT0tum, 2022-02-06:
If it is more convenient for you, I have created a discord channel, so we can share ideas better

FaqT0tum, 2022-02-06:
https://discord.gg/Kguv3ZSP

helicopterguru, 2022-02-06:
> Hello, yes I liked doing it. I don't want to be without these macro keys anymore. They are very useful. Mit freundlichen Grüßen Dirk König helicopterguru ***@***.***> schrieb am So., 6. Feb. 2022, 20:17:
> […](#)
> Here is my version to find. With all changes. I hope that's ok, I do not know how to make it accessible to you. ]( https://github.com/AFUDIrk/Orbion_Space_Mouse-2.2) Awesome, thanks for sharing buddy. When I can I'll look at the Arduino code to see what I need to import to add some macro buttons, as that could be handy from what I am seeing. Ian Contessa — Reply to this email directly, view it on GitHub <[#24 (comment)](https://github.com/FaqT0tum/Orbion_Space_Mouse/issues/24#issuecomment-1030896067)>, or unsubscribe <https://github.com/notifications/unsubscribe-auth/ACZYVEJBFRRDKMFMCUAH55LUZ3COJANCNFSM5NMAVEWA> . You are receiving this because you commented.Message ID: ***@***.***>

For sure its going to be an addition ill add to my build some macro buttons. For now wrap it up as is and start using it.

Ian

helicopterguru, 2022-02-06:
> If it is more convenient for you, I have created a discord channel, so we can share ideas better

Hey buddy.

Cool, sounds like a good plan. I've joined the Discord. Will be good to see it expand and more development happen.

Ian

AFUDIrk, 2022-02-07:
Hi,
thank you.

Am So., 6. Feb. 2022 um 22:02 Uhr schrieb FaqTotum ***@***.***
>:

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

Closed 2022-02-06.

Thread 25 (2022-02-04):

Can I use the regular mouse and your 3d mouse at the same time

wprojects, 2022-02-04:
My friend mentioned this mouse is emulated and fusion 360 can only use a single mouse at one time. His concern is that we wouldn't be able to use the 3d mouse while using our regular mouse at the same time. Is it possible to use both orion and a regular mouse simultaneously in fusion 360? Is the mouse emulated or connected like a real mouse? Also do I need to install a driver in linux or windows to get it to work?

FaqT0tum, 2022-02-04:
Orbion uses the Mouse and keyboard libraries, therefore it is possible to use them together without problems as everyone does, obviously if you are doing Orbit and Pan you cannot use the mouse and vice versa. No, there is no need for any driver for any device, the orbion is recognized as a generic mouse and keyboard, you can also use it with smatphones and tablets

Closed 2022-02-04.

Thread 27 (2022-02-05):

OLED stays dark

Davery92, 2022-02-05:
Good Morning, I've been following your project for a while and finally got all the parts necessary. I breadboarded everything this morning and uploaded the sketch after following your wiring schematic, but the OLED stays dark. I've tried two different screens and neither will turn on. The screen will randomly move due to having the joystick at an angle so I know something's wired right and working. Has this ever happened to you?

FaqT0tum, 2022-02-05:
> Good Morning, I've been following your project for a while and finally got all the parts necessary. I breadboarded everything this morning and uploaded the sketch after following your wiring schematic, but the OLED stays dark. I've tried two different screens and neither will turn on. The screen will randomly move due to having the joystick at an angle so I know something's wired right and working. Has this ever happened to you?

the problem can be associated either with the wrong protocol, as there are identical OLEDs but with different controllers (SH1106 and SSD1306) or by the SDA and SCL cables reversed

Somebody1566, 2022-02-07:
Hey Davery, this is common with breadboards and oleds. It will most likely work if you solder it. Same issue happened to me.

Davery92, 2022-02-07:
You were absolutely right. I discovered this late last night while troubleshooting. I'll be soldering everything this week thanks for the help!

Somebody1566, 2022-02-07:
No worries! Happy to help

FaqT0tum, 2022-02-13:
> You were absolutely right. I discovered this late last night while troubleshooting. I'll be soldering everything this week thanks for the help!

If you need more help, I'll be happy to help you on Discord

Closed 2022-02-13.

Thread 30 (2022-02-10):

What i'am doing wrong?

olaf1971229, 2022-02-10:
Hi,
i trying to upload the Firmware Files to the Board.

i get allways the following error(s):

/\/\/\/\/\/\/\/\/\/\/\/\/\/\/\/\/\/\/\/\/\/\/\/\/\/\/\/\
after a looong break........

files are corrupted..........
doing a new download............
all ok

my mistake :-((

/\/\/\/\/\/\/\/\/\/\/\/\/\/\/\/\/\/\/\/\/\/\/\/\/\/\/\/\

Thank you

Closed 2022-02-10.

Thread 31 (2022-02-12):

unable to compile.. multiple errors in the icon.h file

tnap1979, 2022-02-12:
built 2.2, all parts assembled, all libraries installed, icon.h and ino in same folder...
go to verify or compile, and always this /302 error

FaqT0tum, 2022-02-13:
> built 2.2, all parts assembled, all libraries installed, icon.h and ino in same folder... go to verify or compile, and always this /302 error

Log in to Discord so both me and others can help you in the best possible way ... as soon as you log in, share some screenshots in the Help section of Orbion

Closed 2022-02-13.

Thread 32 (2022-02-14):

'Mouse' not found.

Cagedconner, 2022-02-14:
Arduino: 1.8.19 (Windows 10), Board: "Arduino Nano, ATmega328P"

In file included from D:\Downloads\Orbion_Space_Mouse-main (1)\Orbion_Space_Mouse-main\Orbion_Firmware\Orbion_FW_v0.26.2\Orbion_FW_v0.26.2.ino:8:0:

C:\Users\Conner\Documents\Arduino\libraries\Adafruit_SSD1306/Adafruit_SSD1306.h:63:0: warning: "BLACK" redefined

 #define BLACK SSD1306_BLACK     ///< Draw 'off' pixels

In file included from D:\Downloads\Orbion_Space_Mouse-main (1)\Orbion_Space_Mouse-main\Orbion_Firmware\Orbion_FW_v0.26.2\Orbion_FW_v0.26.2.ino:1:0:

C:\Users\Conner\Documents\Arduino\libraries\Adafruit_SH1106/Adafruit_SH1106.h:48:0: note: this is the location of the previous definition

 #define BLACK 0

In file included from D:\Downloads\Orbion_Space_Mouse-main (1)\Orbion_Space_Mouse-main\Orbion_Firmware\Orbion_FW_v0.26.2\Orbion_FW_v0.26.2.ino:8:0:

C:\Users\Conner\Documents\Arduino\libraries\Adafruit_SSD1306/Adafruit_SSD1306.h:64:0: warning: "WHITE" redefined

 #define WHITE SSD1306_WHITE     ///< Draw 'on' pixels

In file included from D:\Downloads\Orbion_Space_Mouse-main (1)\Orbion_Space_Mouse-main\Orbion_Firmware\Orbion_FW_v0.26.2\Orbion_FW_v0.26.2.ino:1:0:

C:\Users\Conner\Documents\Arduino\libraries\Adafruit_SH1106/Adafruit_SH1106.h:49:0: note: this is the location of the previous definition

 #define WHITE 1

In file included from D:\Downloads\Orbion_Space_Mouse-main (1)\Orbion_Space_Mouse-main\Orbion_Firmware\Orbion_FW_v0.26.2\Orbion_FW_v0.26.2.ino:8:0:

C:\Users\Conner\Documents\Arduino\libraries\Adafruit_SSD1306/Adafruit_SSD1306.h:65:0: warning: "INVERSE" redefined

 #define INVERSE SSD1306_INVERSE ///< Invert pixels

In file included from D:\Downloads\Orbion_Space_Mouse-main (1)\Orbion_Space_Mouse-main\Orbion_Firmware\Orbion_FW_v0.26.2\Orbion_FW_v0.26.2.ino:1:0:

C:\Users\Conner\Documents\Arduino\libraries\Adafruit_SH1106/Adafruit_SH1106.h:50:0: note: this is the location of the previous definition

 #define INVERSE 2

In file included from D:\Downloads\Orbion_Space_Mouse-main (1)\Orbion_Space_Mouse-main\Orbion_Firmware\Orbion_FW_v0.26.2\Orbion_FW_v0.26.2.ino:26:0:

C:\Program Files (x86)\Arduino\libraries\Mouse\src/Mouse.h:29:2: warning: #warning "Using legacy HID core (non pluggable)" [-Wcpp]

 #warning "Using legacy HID core (non pluggable)"

  ^~~~~~~

In file included from D:\Downloads\Orbion_Space_Mouse-main (1)\Orbion_Space_Mouse-main\Orbion_Firmware\Orbion_FW_v0.26.2\Orbion_FW_v0.26.2.ino:27:0:

C:\Program Files (x86)\Arduino\libraries\Keyboard\src/Keyboard.h:29:2: warning: #warning "Using legacy HID core (non pluggable)" [-Wcpp]

 #warning "Using legacy HID core (non pluggable)"

  ^~~~~~~

In file included from D:\Downloads\Orbion_Space_Mouse-main (1)\Orbion_Space_Mouse-main\Orbion_Firmware\Orbion_FW_v0.26.2\Orbion_FW_v0.26.2.ino:30:0:

C:\Users\Conner\Documents\Arduino\libraries\Adafruit_SH1106/Adafruit_SH1106.h:48:0: warning: "BLACK" redefined

 #define BLACK 0

In file included from D:\Downloads\Orbion_Space_Mouse-main (1)\Orbion_Space_Mouse-main\Orbion_Firmware\Orbion_FW_v0.26.2\Orbion_FW_v0.26.2.ino:8:0:

C:\Users\Conner\Documents\Arduino\libraries\Adafruit_SSD1306/Adafruit_SSD1306.h:63:0: note: this is the location of the previous definition

 #define BLACK SSD1306_BLACK     ///< Draw 'off' pixels

In file included from D:\Downloads\Orbion_Space_Mouse-main (1)\Orbion_Space_Mouse-main\Orbion_Firmware\Orbion_FW_v0.26.2\Orbion_FW_v0.26.2.ino:30:0:

C:\Users\Conner\Documents\Arduino\libraries\Adafruit_SH1106/Adafruit_SH1106.h:49:0: warning: "WHITE" redefined

 #define WHITE 1

In file included from D:\Downloads\Orbion_Space_Mouse-main (1)\Orbion_Space_Mouse-main\Orbion_Firmware\Orbion_FW_v0.26.2\Orbion_FW_v0.26.2.ino:8:0:

C:\Users\Conner\Documents\Arduino\libraries\Adafruit_SSD1306/Adafruit_SSD1306.h:64:0: note: this is the location of the previous definition

 #define WHITE SSD1306_WHITE     ///< Draw 'on' pixels

In file included from D:\Downloads\Orbion_Space_Mouse-main (1)\Orbion_Space_Mouse-main\Orbion_Firmware\Orbion_FW_v0.26.2\Orbion_FW_v0.26.2.ino:30:0:

C:\Users\Conner\Documents\Arduino\libraries\Adafruit_SH1106/Adafruit_SH1106.h:50:0: warning: "INVERSE" redefined

 #define INVERSE 2

In file included from D:\Downloads\Orbion_Space_Mouse-main (1)\Orbion_Space_Mouse-main\Orbion_Firmware\Orbion_FW_v0.26.2\Orbion_FW_v0.26.2.ino:8:0:

C:\Users\Conner\Documents\Arduino\libraries\Adafruit_SSD1306/Adafruit_SSD1306.h:65:0: note: this is the location of the previous definition

 #define INVERSE SSD1306_INVERSE ///< Invert pixels

In file included from D:\Downloads\Orbion_Space_Mouse-main (1)\Orbion_Space_Mouse-main\Orbion_Firmware\Orbion_FW_v0.26.2\Orbion_FW_v0.26.2.ino:30:0:

C:\Users\Conner\Documents\Arduino\libraries\Adafruit_SH1106/Adafruit_SH1106.h:141:7: error: redefinition of 'class Adafruit_SH1106'

 class Adafruit_SH1106 : public Adafruit_GFX {

       ^~~~~~~~~~~~~~~

In file included from D:\Downloads\Orbion_Space_Mouse-main (1)\Orbion_Space_Mouse-main\Orbion_Firmware\Orbion_FW_v0.26.2\Orbion_FW_v0.26.2.ino:1:0:

C:\Users\Conner\Documents\Arduino\libraries\Adafruit_SH1106/Adafruit_SH1106.h:141:7: note: previous definition of 'class Adafruit_SH1106'

 class Adafruit_SH1106 : public Adafruit_GFX {

       ^~~~~~~~~~~~~~~

D:\Downloads\Orbion_Space_Mouse-main (1)\Orbion_Space_Mouse-main\Orbion_Firmware\Orbion_FW_v0.26.2\Orbion_FW_v0.26.2.ino: In function 'void setup()':

Orbion_FW_v0.26.2:109:5: error: 'Mouse' not found. Does your sketch include the line '#include <Mouse.h>'?

     Mouse.begin();

     ^~~~~

Orbion_FW_v0.26.2:110:5: error: 'Keyboard' not found. Does your sketch include the line '#include <Keyboard.h>'?

     Keyboard.begin();

     ^~~~~~~~

D:\Downloads\Orbion_Space_Mouse-main (1)\Orbion_Space_Mouse-main\Orbion_Firmware\Orbion_FW_v0.26.2\Orbion_FW_v0.26.2.ino: In function 'void loop()':

Orbion_FW_v0.26.2:136:15: error: 'Keyboard' not found. Does your sketch include the line '#include <Keyboard.h>'?

               Keyboard.press(KEY_LEFT_ALT);

               ^~~~~~~~

Orbion_FW_v0.26.2:136:30: error: 'KEY_LEFT_ALT' was not declared in this scope

               Keyboard.press(KEY_LEFT_ALT);

                              ^~~~~~~~~~~~

Orbion_FW_v0.26.2:138:9: error: 'Mouse' not found. Does your sketch include the line '#include <Mouse.h>'?

         Mouse.move(0, 0, -1);

         ^~~~~

Orbion_FW_v0.26.2:144:15: error: 'Keyboard' not found. Does your sketch include the line '#include <Keyboard.h>'?

               Keyboard.press(KEY_LEFT_ALT);

               ^~~~~~~~

Orbion_FW_v0.26.2:144:30: error: 'KEY_LEFT_ALT' was not declared in this scope

               Keyboard.press(KEY_LEFT_ALT);

                              ^~~~~~~~~~~~

Orbion_FW_v0.26.2:146:11: error: 'Mouse' not found. Does your sketch include the line '#include <Mouse.h>'?

           Mouse.move(0, 0, 1);

           ^~~~~

Orbion_FW_v0.26.2:158:11: error: 'Keyboard' not found. Does your sketch include the line '#include <Keyboard.h>'?

           Keyboard.press(arButt [EEPROM.read(20)]);

           ^~~~~~~~

Orbion_FW_v0.26.2:173:11: error: 'Mouse' not found. Does your sketch include the line '#include <Mouse.h>'?

           Mouse.release(MOUSE_MIDDLE);

           ^~~~~

Orbion_FW_v0.26.2:173:25: error: 'MOUSE_MIDDLE' was not declared in this scope

           Mouse.release(MOUSE_MIDDLE);

                         ^~~~~~~~~~~~

D:\Downloads\Orbion_Space_Mouse-main (1)\Orbion_Space_Mouse-main\Orbion_Firmware\Orbion_FW_v0.26.2\Orbion_FW_v0.26.2.ino:173:25: note: suggested alternative: 'MOUSE_h'

           Mouse.release(MOUSE_MIDDLE);

                         ^~~~~~~~~~~~

                         MOUSE_h

Orbion_FW_v0.26.2:174:11: error: 'Keyboard' not found. Does your sketch include the line '#include <Keyboard.h>'?

           Keyboard.releaseAll();

           ^~~~~~~~

Orbion_FW_v0.26.2:185:11: error: 'Keyboard' not found. Does your sketch include the line '#include <Keyboard.h>'?

           Keyboard.press(arButt [EEPROM.read(30)]);

           ^~~~~~~~

Orbion_FW_v0.26.2:200:11: error: 'Mouse' not found. Does your sketch include the line '#include <Mouse.h>'?

           Mouse.release(MOUSE_MIDDLE);

           ^~~~~

Orbion_FW_v0.26.2:200:25: error: 'MOUSE_MIDDLE' was not declared in this scope

           Mouse.release(MOUSE_MIDDLE);

                         ^~~~~~~~~~~~

D:\Downloads\Orbion_Space_Mouse-main (1)\Orbion_Space_Mouse-main\Orbion_Firmware\Orbion_FW_v0.26.2\Orbion_FW_v0.26.2.ino:200:25: note: suggested alternative: 'MOUSE_h'

           Mouse.release(MOUSE_MIDDLE);

                         ^~~~~~~~~~~~

                         MOUSE_h

Orbion_FW_v0.26.2:201:11: error: 'Keyboard' not found. Does your sketch include the line '#include <Keyboard.h>'?

           Keyboard.releaseAll();

           ^~~~~~~~

Orbion_FW_v0.26.2:222:11: error: 'Mouse' not found. Does your sketch include the line '#include <Mouse.h>'?

           Mouse.move(0, (invertMouseY * (YValue / sens)), 0);

           ^~~~~

Orbion_FW_v0.26.2:229:11: error: 'Mouse' not found. Does your sketch include the line '#include <Mouse.h>'?

           Mouse.move((invertMouseX * (XValue / sens)), 0, 0);

           ^~~~~

Orbion_FW_v0.26.2:237:15: error: 'Keyboard' not found. Does your sketch include the line '#include <Keyboard.h>'?

               Keyboard.releaseAll();

               ^~~~~~~~

Orbion_FW_v0.26.2:242:19: error: 'Mouse' not found. Does your sketch include the line '#include <Mouse.h>'?

                   Mouse.release(MOUSE_MIDDLE);

                   ^~~~~

Orbion_FW_v0.26.2:242:33: error: 'MOUSE_MIDDLE' was not declared in this scope

                   Mouse.release(MOUSE_MIDDLE);

                                 ^~~~~~~~~~~~

D:\Downloads\Orbion_Space_Mouse-main (1)\Orbion_Space_Mouse-main\Orbion_Firmware\Orbion_FW_v0.26.2\Orbion_FW_v0.26.2.ino:242:33: note: suggested alternative: 'MOUSE_h'

                   Mouse.release(MOUSE_MIDDLE);

                                 ^~~~~~~~~~~~

                                 MOUSE_h

Orbion_FW_v0.26.2:243:33: error: 'MOUSE_LEFT' was not declared in this scope

                   Mouse.release(MOUSE_LEFT);

                                 ^~~~~~~~~~

D:\Downloads\Orbion_Space_Mouse-main (1)\Orbion_Space_Mouse-main\Orbion_Firmware\Orbion_FW_v0.26.2\Orbion_FW_v0.26.2.ino:243:33: note: suggested alternative: 'MOUSE_h'

                   Mouse.release(MOUSE_LEFT);

                                 ^~~~~~~~~~

                                 MOUSE_h

Orbion_FW_v0.26.2:244:33: error: 'MOUSE_RIGHT' was not declared in this scope

                   Mouse.release(MOUSE_RIGHT);

                                 ^~~~~~~~~~~

D:\Downloads\Orbion_Space_Mouse-main (1)\Orbion_Space_Mouse-main\Orbion_Firmware\Orbion_FW_v0.26.2\Orbion_FW_v0.26.2.ino:244:33: note: suggested alternative: 'MOUSE_h'

                   Mouse.release(MOUSE_RIGHT);

                                 ^~~~~~~~~~~

                                 MOUSE_h

Orbion_FW_v0.26.2:262:7: error: 'Keyboard' not found. Does your sketch include the line '#include <Keyboard.h>'?

       Keyboard.releaseAll();

       ^~~~~~~~

Orbion_FW_v0.26.2:263:7: error: 'Mouse' not found. Does your sketch include the line '#include <Mouse.h>'?

       Mouse.release(MOUSE_MIDDLE);

       ^~~~~
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
edifabio-72, 2022-02-14:
The microprocessor ATmega328P do not support mouse and keyboard library. It is essential to use ARDUINO PRO MICRO with ATMEL32U4 processor.

FaqT0tum, 2022-02-14:
have you read the guide carefully?  have you read all the disclaimes?  if you need more assistance go to Discord, you will find all the help you need https://discord.gg/KAbUJ2Gr

Cagedconner, 2022-02-14:
Thank you for the quick response, I must have received a different model arduino with my parts order. I assumed my "leonardo" was a pro micro from the store description

Closed 2022-02-15.

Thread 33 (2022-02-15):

Confusion about neopixels

Roycinger, 2022-02-15:
Hi,

first of all this seems to be a great project.
In some pictures, I see a Neopixel strip around the knob axis.
But other than that, I dont see any reference to them.
Not in the BOM, not in the firmware, not in the wiring plan.

Do I miss something here?

Roycinger, 2022-02-15:
Just noticed that Neopixel will be implemented at a later time

Closed 2022-02-15.

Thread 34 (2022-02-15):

Manual?

Sisko4, 2022-02-15:
Is there anywhere a manual that describes what screws go where and also what parts need the insert nuts?
Anything other is absolute clear for me.
Thanks :-)

Sisko4, 2022-02-15:
> If you are able to view the CAD within this repository, using Fusion 360 you can see the inserts in there. In addition, can always join the Discord group @FaqT0tum set up, there's plenty of us who can give you help.

Well...the easy solutions are never available in my own brain^^
Thank you very much!

Roycinger, 2022-02-15:
>
you might close the issue to maintain overview :)

Closed 2022-02-15.

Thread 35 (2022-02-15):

Screen Cover need a little change to prevent screen cracking during install

blaghislain, 2022-02-15:
I wasn't able to install Oled inside screen cover with having it to crack because a portion of plastic (see red part on image) push to much pressure on screen.  After few tries I had to change the STL.

Here (in red) the section that need to be removed
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

Thanks in advance

FaqT0tum, 2022-02-15:
how many mm are there (red part)?

blaghislain, 2022-02-15:
Here are the mesurement
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
Thanks in advance

FaqT0tum, 2022-02-15:
Thank you!  tomorrow afternoon I'll make the change ... now I'm at work until tomorrow 😅

FaqT0tum, 2022-02-16:
I updated the cads with these changes suggested by you, but I haven't published them yet, for other changes to be made ... thanks again

Sisko4, 2022-03-02:
I have the same issue plus the pins don´t fit with the pcb.

FaqT0tum, 2022-03-02:
I'm solving the problem by eliminating the pin method altogether!  if the printer leaves for the confirmation tests I publish the solution as soon as possible

Sisko4, 2022-03-02:
I think the pins aren´t usefull at all, you can also glue the lower part to the base and solve it that way.
Disassembly shouldn´t be a problem that way also for the body.

FaqT0tum, 2022-03-02:
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

Closed 2022-02-16.

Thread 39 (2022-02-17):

Specifiy what type of filament it is expected to be used

VinnyCordeiro, 2022-02-17:
I had fitment issues with all electronic components because I printed the parts in ABS, so that makes me conclude the STL files were made considering that they'll be printed in PLA. Please, specify that on the README.md file.

VinnyCordeiro, 2022-02-17:
PLA have very low shrinkage rates, so you can basically print it as designed. For ABS you have to compensate the shrinkage effect, and that have to be made for each piece, because the shrinkage isn't linear. 😫

FaqT0tum, 2022-02-17:
already, but it is something that you can fix using a slicer.  there is no need to make special files

VinnyCordeiro, 2022-02-17:
Never asked for that, just a note concerning shrinkage of filaments other than PLA.

FaqT0tum, 2022-02-18:
I'll make one in the READEM.md file… ☺️

Closed 2022-02-19.

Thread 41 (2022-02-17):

Why such a restrictive license?

VinnyCordeiro, 2022-02-17:
Having contributed to some open projects, both on software and hardware, it makes me wonder why CC BY-NC-ND 4.0 was chosen. By the terms of the chosen license, I can't fork your repo, make changes, and then commiting those changes on my forked repo without violating it. That greatly stifles contributions from other people that could help enhance this project. Not to mention that all the libraries used on the firmware side are Open Source licenses (GPL v2 or LGPL v2.1 for Arduino libraries, 3-Clause BSD or MIT licenses for Adafruit libraries).

Please don't take that as anything else as an attempt to understand the license choice.

FaqT0tum, 2022-02-17:
the license does not allow remixing, it was decided not to disperse the original project in 1000 forks or remixes on 1000 sites ... as has already been specified in the READEM.md file, you can always contribute to the improvement of the project which remains opensource, just communicate it and I insert it in the parent project.  the libraries I use are freely licensed, including commercial ones.  the project is open source and has not been limited in any way, but has only rules to respect that point only to improvement.  I for one do not ask for money and I dedicate time, renewable energy and investments for a common and not personal factor.  anyway I didn't take it, it's right to have doubts and ask 😋.  I hope I've been exhaustive.

Closed 2022-02-19.

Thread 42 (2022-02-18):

Knob_Axis joystick connection improvements

mace-man, 2022-02-18:
Red -> PLA
Black -> TPU
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
The connection between the joystick and Knob_Axis has been improved.

FaqT0tum, 2022-02-18:
having a flex material at that point does not improve movement but only facilitates the connection between the joystick and the base knob.  the connection must be as rigid as possible as the joystick already has some play

but it's a nice idea.  Well done.  if you want to participate in improving Orbion with lots of ideas, you can join the Discord (find the link on the main page)

Closed 2022-02-18.

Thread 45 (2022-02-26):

Arduino Micro or Leonardo ?

fredmccr, 2022-02-26:
Hi,
I ordered and received my Arduino board from Aliexpress (same link as yours).
It's labeled "Pro Micro" on its top but when I get board info from Arduino IDE, it shows "Arduino Leonardo".
What kind of board should I select before flashing: "Arduino Micro" as stated in the readme file or "Arduino Leonardo" ?
Thanks

kc0rpm, 2022-02-26:
Mine showed up as a Leonardo also. Select micro when uploading code though.

fredmccr, 2022-02-26:
Thank you for your help.
I just flashed my board like you advised. Is it normal now that one of the two red LEDs remains always on ?

kc0rpm, 2022-02-26:
Yeah, thats normal.

Sisko4, 2022-03-04:
I think selecting it as Arduino Micro just briked it. It doesn´t finish uploading.

Sisko4, 2022-03-05:
Does it make any difference anyway if you choose Micro or Leonardo?
Every seller writes you need to choose Leonardo in the Board Selection.

kc0rpm, 2022-03-05:
I don't see why it would. Both boards use the same ATmega32U4 processor. The micro is just a miniaturized version. Of course I could be wrong.

FaqT0tum, 2022-03-08:
the arduino pro micro is a miniaturized leonardo

Closed 2022-03-08.

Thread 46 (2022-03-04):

What is that part on the Micro?

Sisko4, 2022-03-04:
I had to reset my Ardunio Micro because of an user error, after some searching i found out that that part is not the reset switch i first thought, but what is it then?
When i double tapped that chip a few times it looked for me like it resets because the LEDs light up in a certain order.
Could i have damaged that part maybe or is everything okay?

https://abload.de/img/partn8js0.jpg

netweaver1970, 2022-03-04:
It's the external crystal oscillator, needed by the MCU for its proper working. Not a switch...

Closed 2022-03-05.

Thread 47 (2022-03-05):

Recommended Cables

Sisko4, 2022-03-05:
What is the recommended AWG value for the cables?
I have some 30AWG / 0,6mm telephone cables here, but i think they might be to thin for this as they have only one strain (0,25mm), also go right trough the pins of the board.

My cables: https://de.aliexpress.com/i/1005001320739063.html

Amazon or Aliexpress link would be great!

Thanks :-)

FaqT0tum, 2022-03-05:
I added the recommended cable with the link to the parts list.  I recommend a silicone 28awg

Sisko4, 2022-03-05:
Thank you for the fast answer! :-)

Closed 2022-03-05.

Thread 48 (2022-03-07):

Fusion 360 files missing history?

nbering, 2022-03-07:
I would like to make some small corrections to the design to compensate for variability in parts. In this case, I have the following issues that I would have liked to correct for my build:

- The shaft on my encoder is much shorter than the design, so the hole in the Orbion knob barely grabs the top of the shaft, and it comes off easily.
- The alignment for the drill holes on my encoder is out-of-tolerance so that the knob bell doesn't match up to the edge of the base (the base sticks out to the side).
- The PCB for my joystick module is _slightly_ wider than the tolerance allowed in the design, so it doesn't seat into the Arduino's holder.
- I would have liked to adjust the holes for the heat-set insert to match some I keep in stock.

The first two issues could be addressed in the design itself if the base was inset into the knob with a wide vertical and horizontal tolerance. I don't expect to make that change myself.

I wanted to tweak the .f3d file to customize for my build, but everything was solid bodies. There doesn't seem to be a design timeline or any parameters I could adjust. Are they just missing from the export? I've never seen someone build something so complex in mesh mode, so can I assume there were sketches and a design history somewhere?

FaqT0tum, 2022-03-08:
history and status cleared before export due to file weight problems. I work without history, you can too. For the shorter shaft I suggest you buy a longer one because even if you solve the result it will always be disappointing.

nbering, 2022-03-09:
As was pointed out in #20, I bought the encoder linked in the bill-of-materials. I'd have been happy to buy a different part, but I didn't even know I needed to.

FaqT0tum, 2022-03-09:
it is not your fault, but of the shortage that apparently allows the Chinese to pack whatever they find available in good warehouses in order to sell

I am trying to fix this situation but it is not easy to understand when the Chinese pack what you buy.  with other users we have already tried to stem this problem, the only solution is to extrude the 3 / 4mm internal slot of the D-shaft.  but unfortunately this way you have little support surface.  if you can wait for the new version I'm preparing

FaqT0tum, 2022-03-09:
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

FaqT0tum, 2022-03-09:
this is the new upgrade i am preparing.  will change before release but 90% will.  *so don't ask me for files in advance or bom

Closed 2022-03-09.

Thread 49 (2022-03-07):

cushion 3d model fails to print

wprojects, 2022-03-07:
[](https://github.com/FaqT0tum/Orbion_Space_Mouse/blob/main/Orbion_STL/Orbion_Rev2.2/Cushion_HiNATA.stl) This model fails to print no matter which direction I flip it. It even fails when I print it with supports. Does anyone have a version that  will print correctly or can explain to me why this is happening? I am printing in PETG and every other part has printed fine

FaqT0tum, 2022-03-08:
there are many reasons why you can't, but not attributable to the model as we have all printed it without problems. I don't know why you mention PETG, but the cushion has to be molded in TPU

wprojects, 2022-03-08:
@FaqT0tum so I have to print that part in TPU in order to get it to work?

Closed 2022-03-08.

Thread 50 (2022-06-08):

icon.h issue

PickleRick55, 2022-06-08:
When trying to compile the firmware I keep running into the same issue. It tells me that the icon.h file doesn't exist or that there is no such file. I followed the instructions on this website and included the file in the same location as the Orbion_FW_v0.26.3.ino file, but am still getting the error message. I have enclose a picture of both the error message and the files that I am storing.  I am also making the older model which is why I am running Arduino. Any help would be apricated.
Thanks,
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

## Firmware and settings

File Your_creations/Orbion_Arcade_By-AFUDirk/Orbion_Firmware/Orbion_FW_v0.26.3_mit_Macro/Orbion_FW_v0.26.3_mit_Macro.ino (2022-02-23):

//Author Mattia Russo aka FaqT0tum
//June 2021
//FREE FOR ANY NON COMMERCIAL PROJECT

#include "icon.h"
#include <EEPROM.h>
#include <Mouse.h>
#include "Keyboard.h"
#include <Wire.h>
#include <Adafruit_GFX.h>
#include <Adafruit_SH1106.h>                   // Comment if you use SSD1306
//#include <Adafruit_SSD1306.h>                // Uncomment if your oled is SSD1306
#define OLED_RESET 4
Adafruit_SH1106 display(OLED_RESET);           // Comment if you use SSD1306
//Adafruit_SSD1306 display(OLED_RESET);        // Uncomment if your oled is SSD1306
    
String vers = "0.26.3";

/////////////// MACRO KEYBOARD /////////////

char shiftKey = KEY_LEFT_SHIFT;
const int L = 4;      //rot      L für Linie               <------------
const int C = 8;      //gelb     C für Kreis               <------------  
const int R = 9;      //grün     R für Rechteck            <------------
const int E = 21;     //schwarz  E für Extrusion           <------------
const int Q = 10;     //weiß     Q für Drücken/Ziehen      <------------
const int SHIFT = 16; //blau Shift für Taste Schift        <------------   
/////////////// Encoder ////////////////////

int DT = 7;       // Pin  Detect                           <------------
int CLK = 6;      // Pin  Clockwise                        <------------
int encBut = 5;    //Pin encoder Button                    <------------

int encBef = LOW;  
int scr = LOW;            
int encBefClick = 0;     

/////////////// JoyStick ///////////////////

int horzPin = A1;         // Pin Analog output of X        <------------
int vertPin = A2;        // Pin Analog output of Y        <------------
int joyButt = 15;         // Pin Joystick Button           <------------

int moved = 0;        
int YZero, XZero;     
int YValue, XValue;   
int sens = 0;         
int arSens[5] = {125,100,85,60,35};
int used = 0;         
int lastused = 0;     
int offsetJoyX = 15;    // set this value if the joystick moves by itself
int offsetJoyY = 15;    // set this value if the joystick moves by itself

unsigned long tim, h, tim1, h1, tim2, h2;

/////////////// Rear Button  ///////////////

int butFun = 14;   // Pin rear button                      <------------
int butFunBef = 0;  
char arButt [36] = {'q','w','e','r','t','y','u','i','o','p','a','s','d','f','g','h','j','k','l','z','x','c','v','b','n','m','1','2','3','4','5','6','7','8','9','0'};
char cb;

/////////////// Mouse Axis ///////////////////////

int invertMouseX = -1;
int invertMouseY = 1;
int inv = 0;
int smooth = 0;

/////////////// MENU ////////////////////////

int reset = LOW;
int sel = 0;
int exi = LOW;
int first = LOW;
int item = 0;
int on = 1;
int epr = 0;

void setup() 
  {

//////////////// MACRO KEYBOARD //////////////

    pinMode(L, INPUT_PULLUP);
    pinMode(C, INPUT_PULLUP);
    pinMode(R, INPUT_PULLUP);
    pinMode(E, INPUT_PULLUP);
    pinMode(Q, INPUT_PULLUP);
    pinMode(SHIFT, INPUT_PULLUP);							 
    
//////////////////////////////////////////////////////////////////////////// PIN //////////////////////////////////////
    
    pinMode(horzPin, INPUT_PULLUP);        
    pinMode(vertPin, INPUT_PULLUP);
    pinMode(encBut, INPUT_PULLUP);         
    pinMode(butFun, INPUT_PULLUP);        
    pinMode (DT, INPUT);
    pinMode (CLK, INPUT);
    pinMode (joyButt, INPUT_PULLUP);
    
    YZero = analogRead(vertPin);  
    XZero = analogRead(horzPin);  
    scr = digitalRead(DT);
    
//////////////////////////////////////////////////////////////////////////// INITIALIZE ///////////////////////////////
    
    Mouse.begin();      
    Keyboard.begin();   
    
    display.begin(SH1106_SWITCHCAPVCC, 0x3C);             // Comment if you use SSD1306
    //display.begin(SSD1306_SWITCHCAPVCC, 0x3C);          // Uncomment if your oled is SSD1306
    
    display.setRotation(2);
    display.clearDisplay();
  }

void loop() 
  {

/////////////// MACRO KEYBOARD ///////////////

// read the pushbuttons:
  int SHIFT_State = digitalRead(SHIFT);
  int L_State = digitalRead(L);
  int C_State = digitalRead(C);
  int R_State = digitalRead(R);
  int E_State = digitalRead(E);
  int Q_State = digitalRead(Q);  
   
 // _________Shift & 1_________ //
    
     if (SHIFT_State == LOW){
        Keyboard.release(KEY_LEFT_SHIFT);
        Keyboard.press(shiftKey); //press Shift
        Keyboard.press('1');      //press 1
        Keyboard.releaseAll();
        delay(500);
        }
 
 // _____________L____________ //
 
  else if(L_State == LOW){
    Keyboard.press('l'); //press l
    Keyboard.releaseAll();
    delay(500);
    }
   
 // _____________C____________ //
 
  else if(C_State == LOW){
    Keyboard.press('c'); //press c
    Keyboard.releaseAll();
    delay(500);
    }
// _____________R____________ //
 
  else if(R_State == LOW){
    Keyboard.press('r'); //press r
    Keyboard.releaseAll();
    delay(500);
    }
// _____________E____________ //
 
  else if(E_State == LOW){
    Keyboard.press('e'); //press e
    Keyboard.releaseAll();
    delay(500);
    }
// _____________Q____________ //
 
  else if(Q_State == LOW){
    Keyboard.press('q'); //press q
    Keyboard.releaseAll();
    delay(500);
    }
   else {
  Keyboard.releaseAll();
  }
////////////////////////////////////////////////////////////////////////////
  //selSense(&sens);
  sens = arSens[EEPROM.read(0)];
  
  YValue = analogRead(vertPin) - YZero;  
  XValue = analogRead(horzPin) - XZero;

//////////////////////////////////////////////////////////////////////////// SCROLL ///////////////////////////////////

  scr = digitalRead(DT);
  if ((encBef == LOW) && (scr == HIGH)) 
    {
    if (digitalRead(CLK) == LOW) 
      {
        if (EEPROM.read(10) == 4)
            {
              Keyboard.press(KEY_LEFT_ALT);
            }
        Mouse.move(0, 0, -1);
      } 
      else 
        {
          if (EEPROM.read(10) == 4)
            {
              Keyboard.press(KEY_LEFT_ALT);
            }
          Mouse.move(0, 0, 1);
        }
    }
  encBef = scr;
    
//////////////////////////////////////////////////////////////////////////// REAR BUTTON ///////////////////////////////

  if ((digitalRead(butFun) == 0) && (butFunBef == 0)) 
    { 
      butFunBef = 1;
      if (EEPROM.read(20) <=35) 
        {
          Keyboard.press(arButt [EEPROM.read(20)]);
        }
      if (EEPROM.read(20) >=36) 
        {
          epr = 20;
          selButt(&epr);
        }
    }
  else if (digitalRead(butFun) && (butFunBef))
    {
      butFunBef = 0;
      tim2 = millis() - h2;
      if (tim2 > 50)
        {
          h2 = millis();
          Mouse.release(MOUSE_MIDDLE);
          Keyboard.releaseAll();
        }
    }

//////////////////////////////////////////////////////////////////////////// CENTRAL BUTTON ///////////////////////////////
  
  if ((digitalRead(encBut) == 0) && (encBefClick == 0)) 
    { 
      encBefClick = 1;
      if (EEPROM.read(30) <=35) 
        {
          Keyboard.press(arButt [EEPROM.read(30)]);
        }
      if (EEPROM.read(30) >=36) 
        {
          epr = 30;
          selButt(&epr);
        }
    }
  else if (digitalRead(encBut) && (encBefClick))
    {
      encBefClick = 0;
      tim2 = millis() - h2;
      if (tim2 > 50)
        {
          h2 = millis();
          Mouse.release(MOUSE_MIDDLE);
          Keyboard.releaseAll();
        }
    }

//////////////////////////////////////////////////////////////////////////// ORBIT & PAN //////////////////////////////
  if(EEPROM.read(10) == 0)
    {
      smooth = 0;
    }
  else
    {
      smooth = 30;
    }
  
  tim = millis() - h;
  if (tim > smooth)
    {
      h = millis();
      if ((YValue > offsetJoyY)||(YValue < (-offsetJoyY)))
        { 
          selModes();
          Mouse.move(0, (invertMouseY * (YValue / sens)), 0); 
          moved=1;
        }
        
      if ((XValue > offsetJoyX)||(XValue < (-offsetJoyX)))
        {  
          selModes();
          Mouse.move((invertMouseX * (XValue / sens)), 0, 0);
          moved=1;
        }
      
      if ( (YValue <= offsetJoyY)&&(YValue >= (-offsetJoyY))  &&  (XValue <= offsetJoyX)&&(XValue >= (-offsetJoyX)))
        {  
          if ( (digitalRead(encBut) == 1) && (digitalRead(butFun) == 1) || (EEPROM.read(10) == 4) )
            {
              Keyboard.releaseAll();
              tim1 = millis() - h1;
              if (tim1 > 120)
                {
                  h1 = millis();
                  Mouse.release(MOUSE_MIDDLE);
                  Mouse.release(MOUSE_LEFT);
                  Mouse.release(MOUSE_RIGHT);
                }
            }
          
        }
     }

     
//////////////////////////////////////////////////////////////////////////// MAIN /////////////////////////////////////

    
  if(first == LOW)
    {
      start(&first);
    } 
  if((digitalRead(joyButt) == LOW) && (digitalRead(butFun)== LOW))
    {
      delay(500);
      Keyboard.releaseAll();
      Mouse.release(MOUSE_MIDDLE);
      Mouse.release(MOUSE_LEFT);
      Mouse.release(MOUSE_RIGHT);
      do
        {
          item = 5; //////////////////// item main menu
          rotaryMenu(&sel, &item);
          menu(&sel, &exi, &first);
        }
      while (exi==LOW);
    }
  exi = LOW;
  sel = 0;
  }

void start(int* f) 
  {
    int i = 0;
    if(on == 1)
      {
        do
          {
            display.clearDisplay();
            display.drawBitmap(0, 0, faq, 12*i, 6*i, WHITE);
            display.display();
            i++;
          }
        while(i != 20);  
        on = 0;
      }
    display.clearDisplay();
    display.drawBitmap(0, 0, faq, 128, 64, WHITE);
    display.display();
    *f=1;
  }

///////////////////////////////////////////////////////////////////////////  MENU /////////////////////////////////////

void rotaryMenu(int* s, int* i) 
  {
    if((digitalRead(DT) == HIGH) && (digitalRead(CLK) == LOW) && (reset == LOW))
      {
        if(*s<=(*i-2))
          {
            *s = *s +1;
          }
        reset = HIGH;
      }
    if((digitalRead(DT) == LOW) && (digitalRead(CLK) == HIGH) && (reset == LOW))
      {
        if((*s<=(*i-1)) && (*s>0)) //set number of item
          {
            *s = *s -1;
          }
        else
          {
            *s=0;  
          }
        reset = HIGH;
      }
    if(digitalRead(DT) && digitalRead(CLK))
      {
        reset = LOW;
      }
  }

void menu(int* s, int* e, int* f)
  {
    switch (*s)
      {
        case 0:
          display.clearDisplay();
          display.setTextColor(WHITE);
          display.setTextSize(2);
          display.setCursor(11,25);
          display.println("Joy Sense");
          display.display();
          if(digitalRead(butFun)==LOW)
            {
              joySens();
            }
        break;
  
        case 1:
          display.clearDisplay();
          display.setTextColor(WHITE);
          display.setTextSize(2);
          display.setCursor(16,25);
          display.println("Joy Mode");
          display.display();
          if(digitalRead(butFun)==LOW)
            {
              joyMode();
            }
        break;
  
        case 2:
          display.clearDisplay();
          display.setTextColor(WHITE);
          display.setTextSize(2);
          display.setCursor(10,25);
          display.println("Knob Push");
          display.display();
          if(digitalRead(butFun)==LOW)
            {
              epr = 30;
              buttMode(&epr);
            }
        break;
  
        case 3:
          display.clearDisplay();
          display.setTextColor(WHITE);
          display.setTextSize(2);
          display.setCursor(10,25);
          display.println("Rear Push");
          display.display();
          if(digitalRead(butFun)==LOW)
            {
              epr = 20;
              buttMode(&epr);
            }
        break;
  
        case 4:
          display.clearDisplay();
          display.drawBitmap(0, 0, ext, 128, 64, WHITE);
          display.setTextColor(WHITE);
          display.setTextSize(1);
          display.setCursor(47,54);
          display.println(vers);
          display.display();
          if(digitalRead(butFun)==LOW)
            {
              *e = HIGH;
            }
        break;
      }
    *f = LOW;
  }


/////////////////////////////////////////////////////////////////////////// JOY MODES /////////////////////////////////

void joyMode()
  {
    int t = EEPROM.read(10);
    int ex = LOW;
    delay(300);
    do 
      {
        display.clearDisplay();
        display.setTextColor(WHITE);
        display.setTextSize(2);
        display.setCursor(16,10);
        display.println("Joy Mode");
        if(t == 0)
          { 
            display.setCursor(33,35);
            display.print("Mouse");
          }
        if(t == 1)
          {
            display.setCursor(17,35);
            display.print("Autodesk");
          }
        if(t == 2)
          {
            display.setCursor(10,35);
            display.print("Solid W/E");
          }
        if(t == 3)
          {
            display.setCursor(23,35);
            display.print("Blender");
          }
        if(t == 4)
          {
            display.setCursor(33,35);
            display.print("Adobe");
          }
        if(t == 5)
          {
            display.setCursor(23,35);
            display.print("FreeCad");
          }
        if(t == 6)
          {
            display.setCursor(33,35);
            display.print("Rhino");
          }
        if(t == 7)
          {
            display.setCursor(28,35);
            display.print("ZBrush");
          }
        if(t == 8)
          {
            display.setCursor(41,35);
            display.print("ANSA");
          }
        if(t == 9)
          {
            display.setCursor(23,35);
            display.print("Onshape");
          }
        display.display();
        item = 10;                     //number of modes
        rotaryMenu(&t, &item); 
        Serial.println(t);                   
        if(digitalRead(butFun)==LOW)
          {
            ex = HIGH;
            EEPROM.update(10, t);
          }
      }
    while (ex == LOW);
    delay(300);
  }

void selModes()
  {
  switch (EEPROM.read(10))
    {
      case 0:
        //mouse mode
      break;

      case 1:
        //Autodesk
        Keyboard.press(KEY_LEFT_SHIFT);
        Mouse.press(MOUSE_MIDDLE);
      break;

      case 2:
        //Solid Work/Edge
        Mouse.press(MOUSE_MIDDLE);
      break;

      case 3:
        //Blender
        Keyboard.press(KEY_LEFT_SHIFT);
        Keyboard.press(KEY_LEFT_ALT);
        Mouse.press(MOUSE_MIDDLE);
      break;

      case 4:
        //Adobe
        Keyboard.press(32);
        Mouse.press(MOUSE_LEFT);
      break;

      case 5:
        //Freecad
        Mouse.press(MOUSE_MIDDLE);
        Mouse.press(MOUSE_RIGHT);
      break;

      case 6:
        //Rhino
        Mouse.press(MOUSE_RIGHT);
      break;

      case 7:
        //ZBrush
        Mouse.press(MOUSE_LEFT);
      break;

      case 8:
        //ANSA
        Keyboard.press(KEY_LEFT_CTRL);
        Mouse.press(MOUSE_LEFT);
      break;

      case 9:
        //Onshape
        Mouse.press(MOUSE_RIGHT);
        break;
    }  
  }

/////////////////////////////////////////////////////////////////////////// JOY SENSE /////////////////////////////////

void joySens()
  {
  int ex2 = LOW; 
  int t = EEPROM.read(0);
  delay(300);
  do 
    {
    display.clearDisplay();
    display.setTextColor(WHITE);
    display.setTextSize(2);
    display.setCursor(10,10);
    display.println("Joy Sense");
    display.setCursor(56,35);
    display.print(t+1);
    display.display();
    item = 5;
    rotaryMenu(&t, &item);
    if(digitalRead(butFun)==LOW)
      {
      ex2=HIGH;
      EEPROM.update(0, t);
      }
    }
  while (ex2==LOW);
  delay(300);
  ex2=LOW;
  }

/////////////////////////////////////////////////////////////////////////// BUTTON MODE /////////////////////////////////

void buttMode(int *e)
  {
    int ex = LOW;
    int t = EEPROM.read(*e);
    delay(500);
    do 
      {
        display.clearDisplay();
        display.setTextColor(WHITE);
        display.setTextSize(2);
        display.setCursor(10,10);
        display.println("SELECT FN");
        if (t <= 35)
          {
            display.setCursor(58,35);
            display.print(arButt[t]);
          }
        if (t == 36)
          {
            display.setCursor(36,35);
            display.print("Space");
          }
        if (t == 37)
          {
            display.setCursor(45,35);
            display.print("CTRL");
          }
        if (t == 38)
          {
            display.setCursor(37,35);
            display.print("Shift");
          }
        if (t == 39)
          {
            display.setCursor(48,35);
            display.print("Alt");
          }
        if (t == 40)
          {
            display.setCursor(48,35);
            display.print("Tab");
          }
        if (t == 41)
          {
            display.setCursor(49,35);
            display.print("Esc");
          }
        if (t == 42)
          {
            display.setCursor(49,35);
            display.print("Del");
          }
        if (t == 43)
          {
            display.setCursor(31,35);
            display.print("Scroll");
          }
        if (t == 44)
          {
            display.setCursor(10,35);
            display.print("Solid W/E");
          }
        if (t == 45)
          {
            display.setCursor(41,35);
            display.print("ANSA");
          }
        display.display();
        item = 46;
        rotaryMenu(&t, &item);
        if(digitalRead(butFun)==LOW)
          {
            ex = HIGH;
            EEPROM.update(*e, t);
          }
      }
    while (ex == LOW);
    delay(300);
  }

void selButt(int *e)
  {
  switch (EEPROM.read(*e))
      {
        case 36:
          Keyboard.press(32);          
        break;
  
        case 37:
          Keyboard.press(KEY_LEFT_CTRL);
        break;
  
        case 38:
          Keyboard.press(KEY_LEFT_SHIFT);
        break;
  
        case 39:
          Keyboard.press(KEY_LEFT_ALT);
        break;
  
        case 40:
          Keyboard.press(KEY_TAB);
        break;
  
        case 41:
          Keyboard.press(KEY_ESC);
        break;
  
        case 42:
          Keyboard.press(KEY_DELETE);
        break;

        case 43:
          Mouse.press(MOUSE_MIDDLE);
        break;

        case 44:
          Keyboard.press(KEY_LEFT_GUI);
          Mouse.press(MOUSE_MIDDLE);
        break;
          
        case 45:
          Keyboard.press(KEY_LEFT_CTRL);
          Mouse.press(MOUSE_MIDDLE);
        break;
      } 
  }

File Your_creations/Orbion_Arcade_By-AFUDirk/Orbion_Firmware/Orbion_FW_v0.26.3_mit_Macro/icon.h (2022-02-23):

#ifndef ICON_H
#define ICON_H

#define faq_BMPWIDTH 128
#define faq_BMPHEIGHT 64
const unsigned char faq[] PROGMEM = {
  0x00, 0x00, 0x00, 0x00, 0x00, 0x00, 0x00, 0x00, 0x00, 0x00, 0x00, 0x00, 0x00, 0x00, 0x00, 0x00, 
  0x00, 0x00, 0x00, 0x00, 0x00, 0x00, 0x00, 0x00, 0x00, 0x00, 0x00, 0x00, 0x00, 0x00, 0x00, 0x00, 
  0x00, 0x00, 0x00, 0x00, 0x00, 0x00, 0x00, 0x00, 0x00, 0x00, 0x00, 0x00, 0x00, 0x00, 0x00, 0x00, 
  0x00, 0x00, 0x00, 0x00, 0x00, 0x00, 0x00, 0x00, 0x00, 0x00, 0x00, 0x00, 0x00, 0x00, 0x00, 0x00, 
  0x00, 0x00, 0x00, 0x00, 0x00, 0x00, 0x00, 0x00, 0x00, 0x00, 0x00, 0x00, 0x00, 0x00, 0x00, 0x00, 
  0x00, 0x00, 0x00, 0x00, 0x00, 0x00, 0x00, 0x00, 0x00, 0x00, 0x00, 0x00, 0x00, 0x00, 0x00, 0x00, 
  0x00, 0x00, 0x00, 0x00, 0x00, 0x00, 0x00, 0x00, 0x00, 0x00, 0x00, 0x00, 0x00, 0x00, 0x00, 0x00, 
  0x00, 0x00, 0x00, 0x00, 0x00, 0x00, 0x00, 0x00, 0x00, 0x00, 0x00, 0x00, 0x00, 0x00, 0x00, 0x00, 
  0x00, 0x00, 0x00, 0x00, 0x7f, 0xff, 0xff, 0xff, 0xff, 0xff, 0xff, 0xfe, 0x00, 0x00, 0x00, 0x00, 
  0x00, 0x00, 0x00, 0x00, 0xf0, 0x00, 0x00, 0x00, 0x00, 0x00, 0x00, 0x0f, 0x00, 0x00, 0x00, 0x00, 
  0x00, 0x00, 0x00, 0x00, 0xc0, 0x00, 0x00, 0x00, 0x00, 0x00, 0x00, 0x03, 0x00, 0x00, 0x00, 0x00, 
  0x00, 0x00, 0x00, 0x01, 0x9f, 0xff, 0xff, 0xff, 0xff, 0xff, 0xff, 0xf9, 0x80, 0x00, 0x00, 0x00, 
  0x00, 0x00, 0x00, 0x01, 0x9f, 0xff, 0xff, 0xff, 0xff, 0xff, 0xff, 0xf9, 0x80, 0x00, 0x00, 0x00, 
  0x00, 0x00, 0x00, 0x01, 0x9f, 0xff, 0xff, 0xff, 0xff, 0xff, 0xff, 0xf9, 0x80, 0x00, 0x00, 0x00, 
  0x00, 0x00, 0x00, 0x01, 0x9f, 0xff, 0xff, 0xff, 0xff, 0xff, 0xff, 0xf9, 0x80, 0x00, 0x00, 0x00, 
  0x00, 0x00, 0x00, 0x01, 0x9f, 0xff, 0xff, 0xff, 0xff, 0xff, 0xff, 0xf9, 0x80, 0x00, 0x00, 0x00, 
  0x00, 0x00, 0x00, 0x01, 0x9f, 0xff, 0xff, 0xff, 0xff, 0xff, 0xff, 0xf9, 0x80, 0x00, 0x00, 0x00, 
  0x00, 0x00, 0x00, 0x01, 0x9f, 0xc0, 0x00, 0x00, 0x00, 0x00, 0x00, 0x01, 0x80, 0x00, 0x00, 0x00, 
  0x00, 0x00, 0x00, 0x01, 0x9f, 0x80, 0x00, 0x00, 0x00, 0x00, 0x00, 0x01, 0x80, 0x00, 0x00, 0x00, 
  0x00, 0x00, 0x00, 0x01, 0x9f, 0x80, 0x00, 0x00, 0x00, 0x00, 0x00, 0x01, 0x80, 0x00, 0x00, 0x00, 
  0x00, 0x00, 0x00, 0x01, 0x9f, 0x80, 0x00, 0x00, 0x00, 0x00, 0x00, 0x01, 0x80, 0x00, 0x00, 0x00, 
  0x00, 0x00, 0x00, 0x01, 0x9f, 0x80, 0x00, 0x00, 0x00, 0x00, 0x00, 0x01, 0x80, 0x00, 0x00, 0x00, 
  0x00, 0x00, 0x00, 0x01, 0x9f, 0xc0, 0x00, 0x00, 0x00, 0x00, 0x00, 0x01, 0x80, 0x00, 0x00, 0x00, 
  0x00, 0x00, 0x00, 0x01, 0x9f, 0xff, 0xff, 0xff, 0x07, 0xff, 0xff, 0x01, 0x80, 0x00, 0x00, 0x00, 
  0x00, 0x00, 0x00, 0x01, 0x9f, 0xff, 0xff, 0xff, 0x87, 0xff, 0xff, 0x01, 0x80, 0x00, 0x00, 0x00, 
  0x00, 0x00, 0x00, 0x01, 0x9f, 0xff, 0xff, 0xff, 0x87, 0xff, 0xff, 0x01, 0x80, 0x00, 0x00, 0x00, 
  0x00, 0x00, 0x00, 0x01, 0x9f, 0xff, 0xff, 0xff, 0x87, 0xff, 0xff, 0x01, 0x80, 0x00, 0x00, 0x00, 
  0x00, 0x00, 0x00, 0x01, 0x9f, 0xff, 0xff, 0xff, 0x87, 0xff, 0xff, 0x01, 0x80, 0x00, 0x00, 0x00, 
  0x00, 0x00, 0x00, 0x01, 0x9f, 0xff, 0xff, 0xff, 0x87, 0xff, 0xff, 0x01, 0x80, 0x00, 0x00, 0x00, 
  0x00, 0x00, 0x00, 0x01, 0x9f, 0xc3, 0xf8, 0x7f, 0x87, 0xf0, 0xff, 0x01, 0x80, 0x00, 0x00, 0x00, 
  0x00, 0x00, 0x00, 0x01, 0x9f, 0x83, 0xf8, 0x3f, 0x87, 0xf0, 0x7f, 0x01, 0x80, 0x00, 0x00, 0x00, 
  0x00, 0x00, 0x00, 0x01, 0x9f, 0x83, 0xf8, 0x3f, 0x87, 0xf0, 0x7f, 0x01, 0x80, 0x00, 0x00, 0x00, 
  0x00, 0x00, 0x00, 0x01, 0x9f, 0x83, 0xf8, 0x3f, 0x87, 0xf0, 0x7f, 0x01, 0x80, 0x00, 0x00, 0x00, 
  0x00, 0x00, 0x00, 0x01, 0x9f, 0x83, 0xf8, 0x7f, 0x87, 0xf0, 0x7f, 0x01, 0x80, 0x00, 0x00, 0x00, 
  0x00, 0x00, 0x00, 0x01, 0x9f, 0x83, 0xff, 0xff, 0x87, 0xf0, 0x7f, 0x01, 0x80, 0x00, 0x00, 0x00, 
  0x00, 0x00, 0x00, 0x01, 0x9f, 0x83, 0xff, 0xff, 0x87, 0xf0, 0x7f, 0x01, 0x80, 0x00, 0x00, 0x00, 
  0x00, 0x00, 0x00, 0x01, 0x9f, 0x83, 0xff, 0xff, 0x87, 0xf0, 0x7f, 0x01, 0x80, 0x00, 0x00, 0x00, 
  0x00, 0x00, 0x00, 0x01, 0x9f, 0x83, 0xff, 0xff, 0x87, 0xf0, 0x7f, 0x01, 0x80, 0x00, 0x00, 0x00, 
  0x00, 0x00, 0x00, 0x01, 0x9f, 0x83, 0xff, 0xff, 0x87, 0xf0, 0x7f, 0x01, 0x80, 0x00, 0x00, 0x00, 
  0x00, 0x00, 0x00, 0x01, 0x9f, 0x83, 0xff, 0xff, 0x87, 0xf0, 0x7f, 0x01, 0x80, 0x00, 0x00, 0x00, 
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
  };
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

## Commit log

2021-06-29 Fixed problem suppoero encoder, improved grip Knob
2021-06-29 0.25 (added compatibility, fixed bugs, improve fluency)
    [Orbion_FW_v0.25.ino, icon.h]
2021-07-13 Update and rename Orbion_FW_v0.25.ino to Orbion_FW_v0.25.1.ino
    Fix a Naming into menu
    [Orbion_FW_v0.25.1.ino]
2022-01-18 Minor update
    -Added Joystick modes (Orbit) for Onshape and ANSA
    -Added Knob Button (Pan/Transfer) for ANSA
    -Fix the problem of the keys pressed while entering the menu
    [Orbion_FW_v0.26.ino]
2022-01-21 Add files via upload
    New Restalyng (Rev2)
    [Base.stl, Body.stl, Enc_holder_14.stl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]
2022-01-21 added part for Type-C (Beta)
    Added a base with support for arduino pro micro with Type-c (beta)
2022-01-21 Add files via upload
    Add part for support Arduino Pro Micro with Type-C
2022-01-21 Add files via upload
    Add support for Arduino Pro Micro with Type-C (BETA)
    [Base_MicroUSB.stl, Base_TypeC_BETA.stl, Body.stl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]
2022-02-09 Fix Part + Neopixel support (Coming Soon)
    The following parts have been repaired: Supp_ele; Knob_bel_xxx; Enc_holder_XXmm; Knob_Axis_XXmm. And improved parts for Type-C support which still remains in BETA
    [Base_MicroUSB.stl, Base_TypeC_BETA.stl, Body.stl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]
2022-02-14 Fix Switch(selButt)
